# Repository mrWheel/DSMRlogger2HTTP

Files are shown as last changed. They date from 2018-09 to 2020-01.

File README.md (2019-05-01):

# DSMRlogger2HTTP
This repository contains the software for the *Draadloze Slimme Meter Reader*.

<br />

You can find <i>technical</i> documentation for this project at 
<a href="https://mrWheel.github.io/DSMRlogger2HTTP/">https://mrWheel.github.io/DSMRlogger2HTTP </a>
    
<br />

<div style="background:#ADD8E6;">
<br />
    
There is a new repository with new firmware for de DSMR-logger that you can find 
<a href="https://github.com/mrWheel/DSMRloggerWS">here</a>
<br /> &nbsp;
<br />
</div>

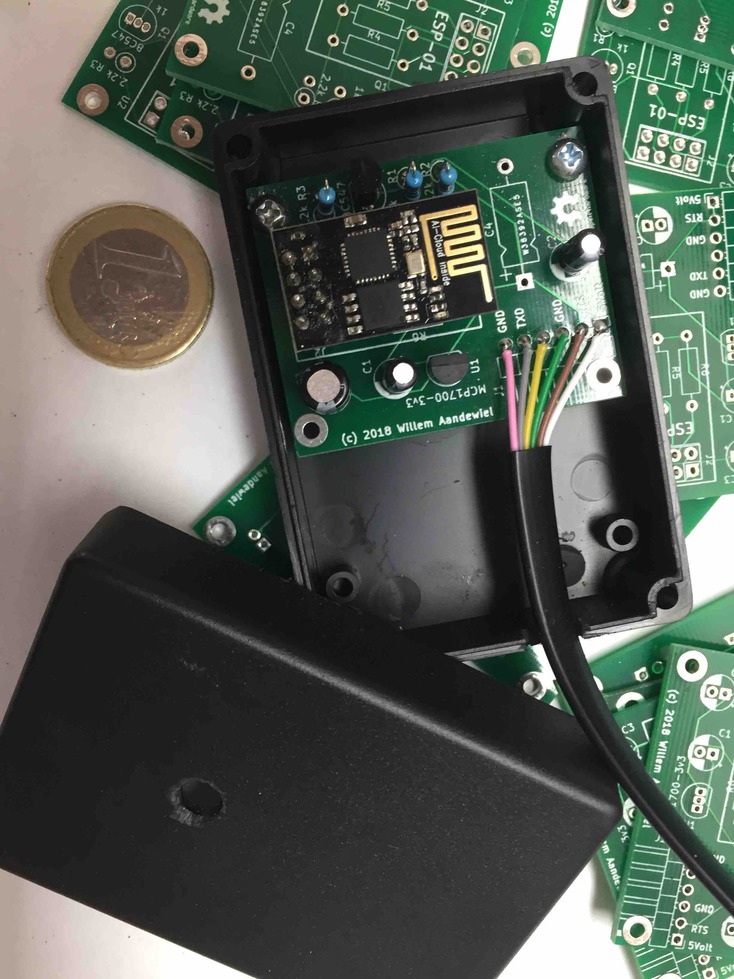
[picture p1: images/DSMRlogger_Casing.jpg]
Completed


Almost all households in the Netherlands are equipped with such a Smart Meter.

The name DSMRlogger is derived from the acronym DSMR which stands for “*Dutch Smart Meter Requirements*“.
The hardware and software should work from **version 4.0** and up of these requirements (as from that version on
the requirements state a 5v output @250mA, which is needed by the DSMRlogger to operate).

Unzip the file into your Arduino Projects directory.

A map "**DSMRlogger2HTML**" will be created with in it all the files necessary to program an ESP01
to function as a “*Slimme Meter Uitlezer*”.

If you use an **ESP01 black** (recommended) than you **must** set the board to:

<code>
Arduino-IDE settings for ESP01 (black):

    - Board: "Generic ESP8266 Module"
    - Flash mode: "DOUT"
    - Flash size: "1M (128K SPIFFS)"
    - Debug port: "Disabled"
    - Debug Level: "None"
    - IwIP Variant: "v2 Lower Memory"
    - Reset Method: "nodemcu"   // <-- this actualy depends on the programmer you use
    - Crystal Frequency: "26 MHz"
    - Flash Frequency: "40MHz"
    - CPU Frequency: "80 MHz"
    - Buildin Led: "1"  // GPIO01 - Pin 2
    - Upload Speed: "115200"
    - Erase Flash: "Only Sketch"
    - Port: "ESP01-DSMR at <-- IP address →"
</code>

For more information see [this post](https://willem.aandewiel.nl/index.php/slimme-meter-uitlezer/).

If you are new to programming the ESP8266 (and you have mastered the Dutch language) I recoment 
[this](https://willem.aandewiel.nl/index.php/aan-de-slag-met-de-esp8266/) post!

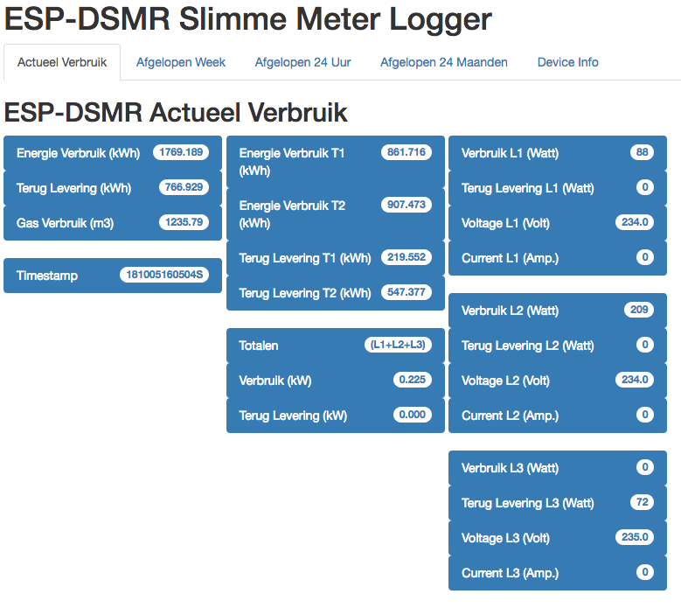
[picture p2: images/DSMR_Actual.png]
Actual

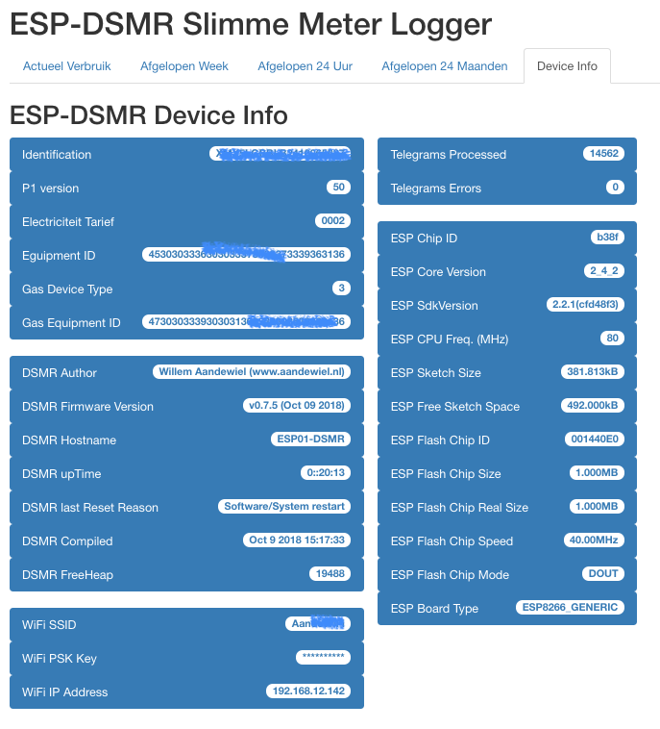
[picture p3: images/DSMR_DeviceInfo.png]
DeviceInfo


If you upload one of the <code>PRDfiles.csv</code>, you need to reboot the ESP01-DSMR before it overwrites the files again from memory to SPIFFS (every change of the hour, day or month).

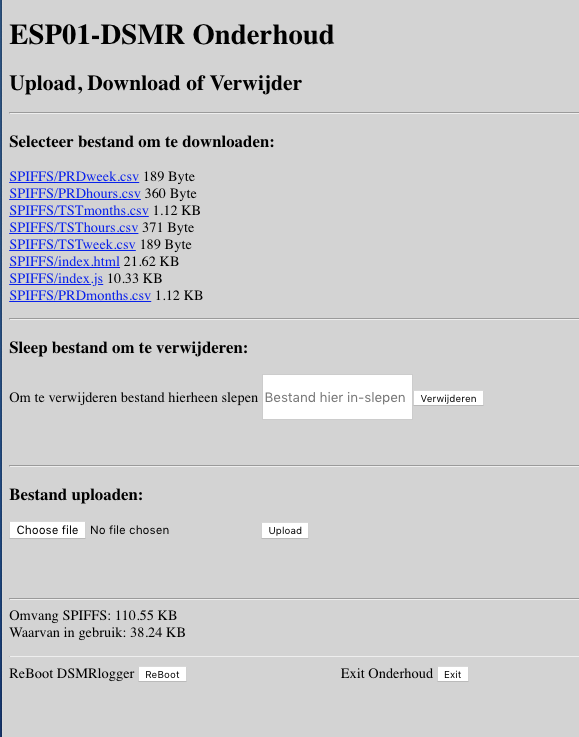
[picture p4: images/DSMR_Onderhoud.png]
Onderhoud


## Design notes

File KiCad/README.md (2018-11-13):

# DSMR-logger PCB v3.0

Here you will find the gerber files for the DSMR-logger

Main changes are:

     - RJ12 connector in stead of soldering the connector wires directly to the PCM
     - Pads for U1 are now further apart
     - Pads for Q1 are now further apart
     - C3 / C2 changed places

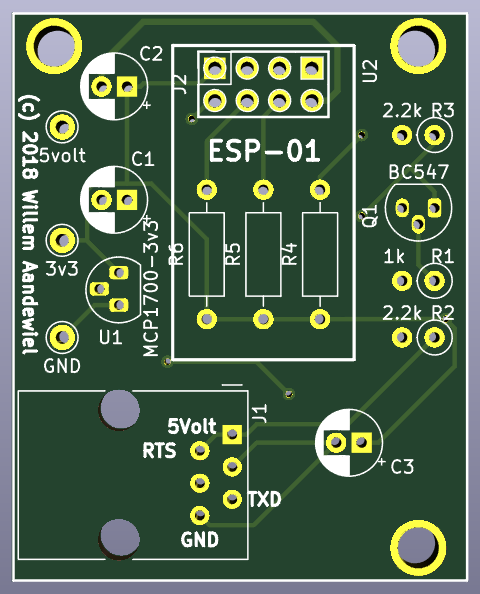
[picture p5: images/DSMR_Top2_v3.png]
Top2

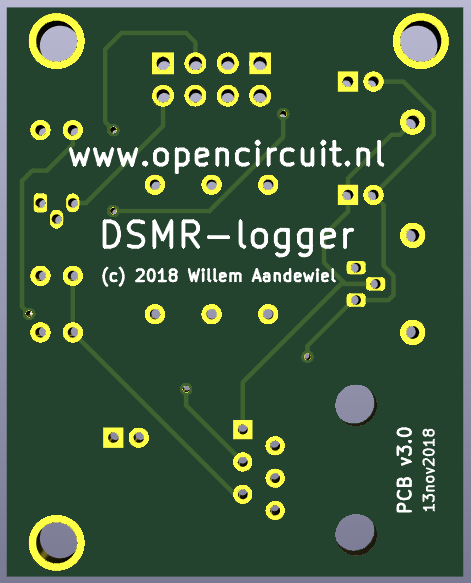
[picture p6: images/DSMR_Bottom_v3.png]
Bottom

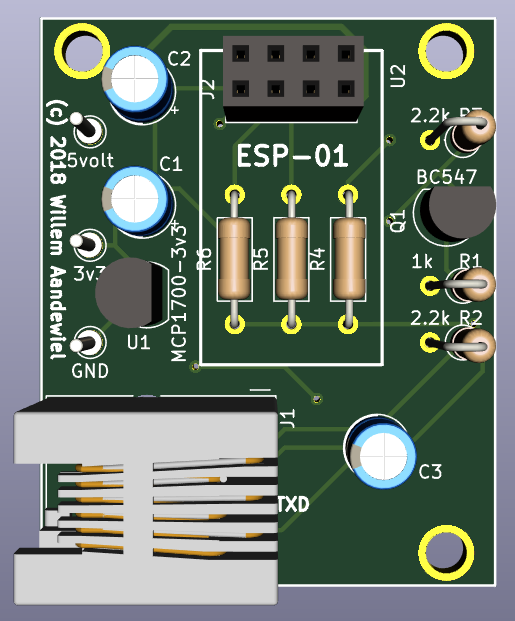
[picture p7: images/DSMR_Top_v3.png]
Top


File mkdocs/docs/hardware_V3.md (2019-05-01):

## DSMR-logger Versie 3

Hoe je een DSMRlogger Versie 2 kunt bouwen staat 
<a href="https://github.com/mrWheel/DSMRlogger2HTTP/blob/master/Bouwbeschrijving.pdf" target="_blank">
hier</a>
uitvoerig beschreven.

Versie 3 is gelijk aan Versie 2 met dit verschil dat de transistor en voltage regulator
eenvoudiger zijn te solderen omdat de pad's verder uit elkaar staan.

Versie 3 heeft ook een RJ12 connector waardoor de draadbreuken die met Versie 2
nog wel eens voorkwamen verleden tijd zijn.

Een bouwpakket voor Versie 3 kun je 
<a href="https://opencircuit.nl/Product/13859/Slimme-meter-uitlezer-V3-bouwpakket-met-ESP-01" target="_blank">
hier</a> bestellen.

### Inhoud Opencircuit bouwpakket 

|Aantal|Itemi |PCB label|
|---|---|---|
|1x|PCB|-|
|1x|ESP8266 ESP-01S|-|
|1x|BC547|Q1|
|1x|MCP1700-3v3|U1|
|1x|1K Ω weerstand (bruin,zwart,rood)|R1|
|2x|2K2 Ω weerstand (rood,rood,rood)|R2,R3|
|3x|10K Ω weerstand (bruin,zwart,oranje)|R4,R5,R6|
|1x|Elco 1µF|C1| 
|1x|Elco 2.2µF|C2| 
|1x|Elco 1000µF|C3| 
|1x|Socket connector 4x2|J2|
|1x|RJ12 Socket connector|J1|
|1x|RJ12 kabel|-|

### Solderen

Begin met de laagste componenten: 

- Plaats: R4, R5 en R6, plaats deze plat. Weerstanden hebben geen polariteit, de richting 
maakt dus niet uit.
- Plaats R1, R2, R3 rechtop. 
- Plaats Q1 en U1 - de soldeer pads zijn klein en liggen dicht bij elkaar, wees 
zorgvuldig en neem de tijd. 

De Elco's hebben wel polariteit, de negatieve pool is herkenbaar aan de lichtere streep op de 
zijkant. Op de PCB is deze kant aangegeven met een witte helft. Daar moet de negatieve pool 
op worden aangesloten.

- Plaats C1, C2 en C3 met de juiste negatieve pool en de correcte Elco.
- Plaats J2 en J1 

Controleer je werk op slechte soldeerverbindingen (het tin droogt dan *mat* op) en
kortsluiting (tin-bruggen tussen twee pad's).

De ESP01 word uiteindelijk in de socket geplaatst, maar moet eerst nog worden geflashed met 
de `DSMRlogger2HTTP` firmware en de `data`-map moet naar SPIFFS worden ge-upload voordat 
hij kan gaan loggen. Hoe dat moet staat [hier](../uploadFirmware_ESP-01) en 
[hier](../uploadDataMap_ESP-01) beschreven.

<br>
---
<center style="font-size: 70%;">[PCB Versie 2]</center><br>

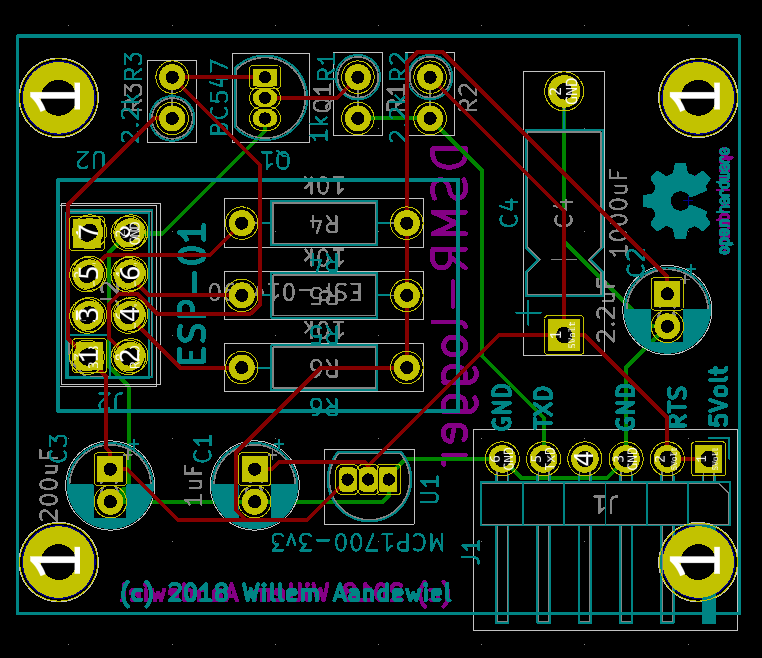
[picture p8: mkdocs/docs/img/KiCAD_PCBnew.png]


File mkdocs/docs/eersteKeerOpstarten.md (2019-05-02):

# Eerste keer opstarten

Haal de ESP01 van de programmer/breadboard af en stop hem in de socket van de logger.
Sluit de logger aan op de P1 poort van de "slimme meter". Hij zal gaan booten en maakt 
zijn eigen accesspoint. Dit kun je zien aan het blauwe ledje wat zal gaan knipperen
en daarna constant blijft branden.

Via je computer/mobiel, bekijk de Wifi netwerken, hier zul je een 
`ESP01‑DSMR‑xx‑<IPaddress>` tussen zien staan: connect aan dit AccessPoint (AP).

Zodra je verbonden bent, open de browser en ga naar ip adres wat de naam van het 
accesspoint staat bijv `192.168.5.1`

- Klik op `Configure WiFi`
- Selecteer je eigen WiFi router
- Typ het password
- Klik save

De logger zal rebooten en verbinding maken met jouw WiFi router

Tijdens het opstarten kun je aan de blauwe led zien wat de DSMR-logger aan het doen is:

- 3 x langzaam knipperen – initiële start
- 5 x snel knipperen – verbinding gemaakt met WiFi netwerk

Daarna knippert de blauwe led iedere keer als er een nieuw telegram verwerkt wordt.

Als de led, na de eerste drie keer langzaam knipperen blijft branden, dan kon de 
DSMR-logger geen verbinding met jouw WiFi netwerk maken en start hij weer zijn eigen 
AP op en zal je WiFi procedure opnieuw moeten doen.

Zodra hij geconnecteerd is open een browser en ga naar:
`http://ESP01-DSMR.local/` of `http://<IPadresVanDeLogger>/`

Als je in de browser de tekst `FileNotFound` ziet, dan ben je waarschijnlijk vergeten 
de Data-map te uploaden met de menu-optie `ESP8266 Sketch Data Upload` in de ArduinoIDE
([kijk hier](uploadDataMap_ESP-01.md) hoe dat moet).

Als alles goed is gegaan zie je in de browser de hoofd-pagina van de DSMR-logger met 
daarin de actuele data uit de Slimme Meter.

Je kunt met `telnet ESP01-DSMR.local` of met `telnet <IPadresVanDeLogger>` inloggen 
op je DSMR-logger en volgen waar de DSMR-logger mee bezig is.

Om te bepalen welk IP is uitgegeven aan de ESP door de DHCP server, kun je in je router 
kijken, of met bijv de Fing app of met `nmap`.

Een andere manier om achter het IP-adres van je DSMR-logger te komen is door de  
ArduinoIDE op te starten. 

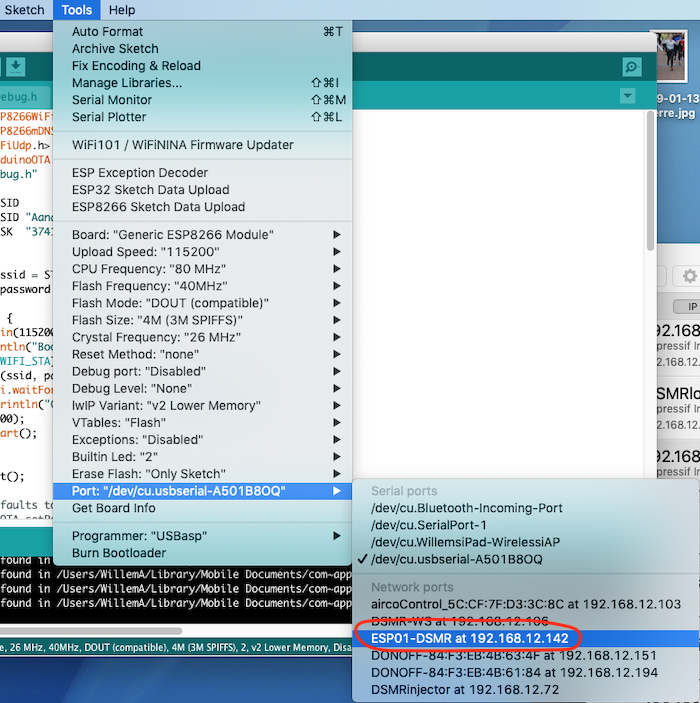
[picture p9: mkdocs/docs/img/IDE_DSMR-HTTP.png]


Onder `Network Ports` staat de `ESP01-DSMR` als optie, met daarachter het IP adres (in dit 
voorbeeld is dat `192.168.12.142`).

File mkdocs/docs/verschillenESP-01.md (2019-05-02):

## Verschillen ESP-01

- ESP-01
- ESP-01 (Black Edition)
- ESP-01S

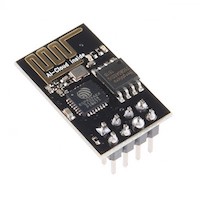
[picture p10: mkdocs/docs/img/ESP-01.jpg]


### ESP-01
De ESP-01 heeft slechts 512MB flash geheugen en is **niet** geschikt voor de DSMR-logger

### ESP-01 (Black Edition)
Dit is de versie van de ESP8266 waar versie 2 en 3 van de DSMR-logger op zijn gebaseerd. 
Deze versie heeft een `rode` power led en een `blauwe` led die op GPIO-01 is 
aangesloten.   
Deze versie heeft `1MB` flash geheugen en is geschikt voor de DSMRlogger2HTTP firmware.

### ESP-01S
Oorspronkelijk had deze ESP-01 ook slecht `512MB` flash geheugen.   
De versie die nu meestal verkocht wordt heeft echter `1MB` geheugen. 
Het is dus wel zaak op te letten wat voor versie je koopt!
De ESP-01S heeft geen power led en de `blauwe led` is niet op GPIO-01 maar op GPIO-02 
aangesloten.  
Deze versie van de ESP-01 is geschikt voor de DSMRlogger2HTTP firmware.

<br>

---
<center style="font-size: 70%">[BOM]<br>
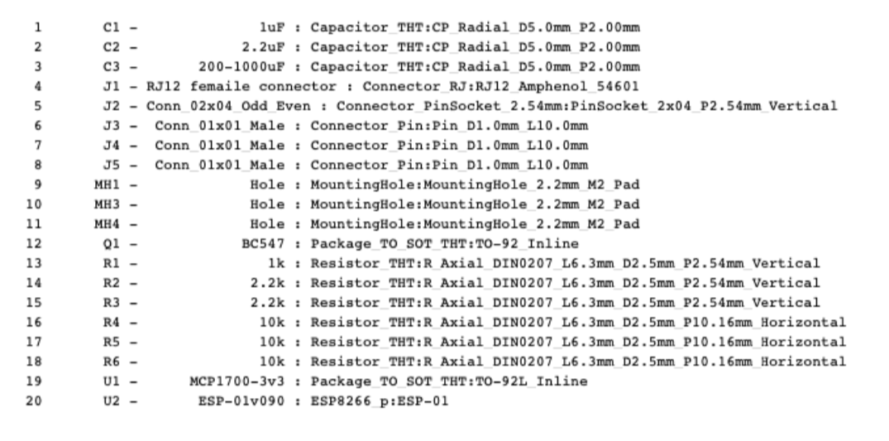
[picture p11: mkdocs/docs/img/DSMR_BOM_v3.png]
</center>

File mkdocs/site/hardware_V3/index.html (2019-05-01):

- Docs »
- Hardware »
- DSMRlogger v3

## DSMR-logger Versie 3

Hoe je een DSMRlogger Versie 2 kunt bouwen staat hier (https://github.com/mrWheel/DSMRlogger2HTTP/blob/master/Bouwbeschrijving.pdf) uitvoerig beschreven.

Versie 3 is gelijk aan Versie 2 met dit verschil dat de transistor en voltage regulator eenvoudiger zijn te solderen omdat de pad's verder uit elkaar staan.

Versie 3 heeft ook een RJ12 connector waardoor de draadbreuken die met Versie 2 nog wel eens voorkwamen verleden tijd zijn.

Een bouwpakket voor Versie 3 kun je hier (https://opencircuit.nl/Product/13859/Slimme-meter-uitlezer-V3-bouwpakket-met-ESP-01) bestellen.

### Inhoud Opencircuit bouwpakket

Aantal | Itemi | PCB label
1x | PCB | -
1x | ESP8266 ESP-01S | -
1x | BC547 | Q1
1x | MCP1700-3v3 | U1
1x | 1K Ω weerstand (bruin,zwart,rood) | R1
2x | 2K2 Ω weerstand (rood,rood,rood) | R2,R3
3x | 10K Ω weerstand (bruin,zwart,oranje) | R4,R5,R6
1x | Elco 1µF | C1
1x | Elco 2.2µF | C2
1x | Elco 1000µF | C3
1x | Socket connector 4x2 | J2
1x | RJ12 Socket connector | J1
1x | RJ12 kabel | -

### Solderen

Begin met de laagste componenten:

- Plaats: R4, R5 en R6, plaats deze plat. Weerstanden hebben geen polariteit, de richting maakt dus niet uit.
- Plaats R1, R2, R3 rechtop.
- Plaats Q1 en U1 - de soldeer pads zijn klein en liggen dicht bij elkaar, wees zorgvuldig en neem de tijd.

De Elco's hebben wel polariteit, de negatieve pool is herkenbaar aan de lichtere streep op de zijkant. Op de PCB is deze kant aangegeven met een witte helft. Daar moet de negatieve pool op worden aangesloten.

- Plaats C1, C2 en C3 met de juiste negatieve pool en de correcte Elco.
- Plaats J2 en J1

Controleer je werk op slechte soldeerverbindingen (het tin droogt dan mat op) en kortsluiting (tin-bruggen tussen twee pad's).

De ESP01 word uiteindelijk in de socket geplaatst, maar moet eerst nog worden geflashed met de DSMRlogger2HTTP firmware en de data-map moet naar SPIFFS worden ge-upload voordat hij kan gaan loggen. Hoe dat moet staat hier en hier beschreven.

[PCB Versie 2]



Next Previous

copyright © 2018 - 2019 Willem Aandewiel

Built with MkDocs (http://www.mkdocs.org) using a theme (https://github.com/snide/sphinx_rtd_theme) provided by Read the Docs (https://readthedocs.org).

« Previous Next »

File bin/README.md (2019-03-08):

# Binary voor ESP-01 

## 1)
Download, als zip file, de laatste versie van DSMRlogger2HTTP van github

### 1.1)
Als je het zipfile download, pak deze dan uit (unzip) en kopieer de map 
```DSMRlogger2HTTP-master``` naar je Arduino projecten directory met de naam ```DSMRlogger2HTTP``` (let
op, het deel '**-master**' moet je dus weghalen!).

In de map staan nu twee andere mappen die van belang zijn. '**/bin**' want hier staat het binary file in dat we naar de ESP-01 gaan uploaden en '**/data**' waar de bestanden voor het file-systeem in staan.

### 1.2)
Je kunt de repository ook clonen. Ga hiervoor in de Arduino projecten directory staan en toets het volgende commando in:

```
    git clone https://github.com/mrWheel/DSMRlogger2HTTP.git
```

Zoek in de (nieuwe) map ```DSMRlogger2HTTP/bin/``` het binary file met de nieuwe firmware. Onthou het pad hier naartoe.

## 2) Voor update "Over The Air":

### 2.1) 
Zoek uit waar jouw versie van '**espota.py**' staat
### 2.2) 
Zoek uit wat het IPaddress van je ESP-01 is (kijk in de IDE bij [port]/[network ports])
### 2.3) 
Onthou waar je de binary van **DSMRlogger2HTTP_v6.ino.bin** heb opgeslagen.
### 2.4) 
Toets het commando in zoals hier onder weergegeven, maar vervang alle variabelen met wat je hiervoor hebt uitgezocht!
```
    python <path naar: 'espota.py'> -i <IPaddress ESP-01> -p 8266 --auth= -f <path naar 'DSMRlogger2HTTP_v6.ino.bin'>
```

*LET OP: de quotjes ('), kleiner-dan (<) en groter-dan (>) tekens moet je niet intoetsen!!*

## 3) Voor update naar een, via een kabel verbonden, programmer voor de ESP-01:

### 3.1)
Zoek uit waar jouw versie van '**esptool**' staat
### 3.2)
Zoek uit op welke (USB)poort de programmer voor de ESP-01 is aangesloten
### 3.3)
Onthou waar je de binary van ```DSMRlogger2HTTP_v6.ino.bin``` heb opgeslagen.
### 3.4)
Toets het commando in zoals hier onder weergegeven, maar vervang alle variabelen met wat je hiervoor hebt uitgezocht!

```
  <path naar: 'esptool'> -vv -cd nodemcu -cb 115200 -cp <USBpoort> -ca 0x00000 -cf <path naar 'DSMRlogger2HTTP_v6.ino.bin'>
```

*LET OP: de quotjes ('), kleiner-dan (<) en groter-dan (>) tekens moet je niet intoetsen!!*

## 4)
Start nu de ArduinoIDE op, selecteer het programma ```DSMRlogger2HTTP```.

## 5)
Selecteer in [**Tools**] de correcte settings voor het ESP-01 board.

    - Board: "Generic ESP8266 Module"
    - Flash mode: "DOUT"
    - Flash size: "1M (128K SPIFFS)"
    - Debug port: "Disabled"
    - Debug Level: "None"
    - IwIP Variant: "v2 Lower Memory"
    - Reset Method: "nodemcu"   // <-- dit is afhankelijk van de programmer die je gebruikt
    - Crystal Frequency: "26 MHz" (otherwise Serial output is garbidge)
    - VTables: "Flash"
    - Flash Frequency: "40MHz"
    - CPU Frequency: "80 MHz"
    - Buildin Led: "1"  // GPIO01 - Pin 2
    - Upload Speed: "115200"
    - Erase Flash: "Only Sketch"
    - Port: "ESP01-DSMR at <-- IP address -->" of USB poort

Klik nu [**Tools**] -> [**ESP8266 Sketch Data Upload**] aan. Nu wordt het filesysteem, inclusief de benodigde bestanden (met name **index.html** en **index.js**) in het SPIFFS bestands-systeem gezet!

## 6)
Klaar!

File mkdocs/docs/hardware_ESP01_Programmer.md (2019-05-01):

## Programmer voor de ESP-01

Je kunt 
<a href="https://willem.aandewiel.nl/index.php/2018/08/27/eenvoudige-programmer-voor-de-esp-01-esp8266/" target="_blank">hier</a>
(www.aandewiel.nl) een post vinden met instructies hoe je eenvoudige een programmer
voor de ESP-01 kunt maken.

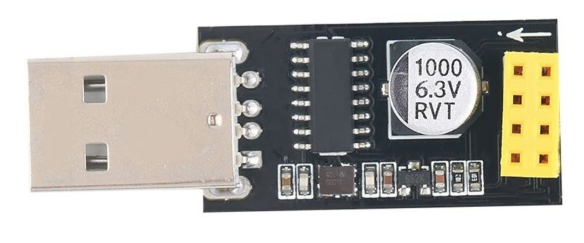
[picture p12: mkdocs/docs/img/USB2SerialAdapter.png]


<br>

---
<center style="font-size: 70%;">[DSMR-logger v3]</center><br>



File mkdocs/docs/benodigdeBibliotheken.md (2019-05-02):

## Benodigde Bibliotheken

Voor de **DSMRlogger2HTTP** firmware zijn de volgende bibliotheken nodig:

### dsmr
Deze library is ontwikkeld door *Matthijs Kooijman* en vormt het hart van de
DSMR-logger. Je kunt de bibliotheek hier
<a href="https://github.com/matthijskooijman/arduino-dsmr" target="_blank">
https://github.com/matthijskooijman/arduino-dsmr</a>
downloaden.   
De firmware is getest met `Version 0.1 - Commit f79c906 on 18 Sep 2018`.

### TimeLib
Deze is door *Paul Stoffregen* ontwikkeld. Je kunt hem hier
<a href="https://github.com/PaulStoffregen/Time" target="_blank">
https://github.com/PaulStoffregen/Time</a>
downloaden.

### WiFiManager
Je kunt de, door *Tzapu* ontwikkelde, bibliotheek hier
<a href="https://github.com/tzapu/WiFiManager" target="_blank">
https://github.com/tzapu/WiFiManager</a>
downloaden.   
De DSMR-logger firmware is getest met `version 0.14.0` van deze bibliotheek.

### TelnetStream
Deze bibliotheek is door *Jan Drassy* ontwikkeld.
Je kunt deze bibliotheek hier
<a href="https://github.com/jandrassy/TelnetStream" target="_blank">
https://github.com/jandrassy/TelnetStream</a>
downloaden.   
De firmware is getest met `version 0.0.1`.

**Let op:** De installatie van deze bibliotheek gaat net als de andere bibliotheken. Een update 
kan echter pas geïnstalleerd worden als éérst de map `TelnetStream-master` uit de
map `Libraries` wordt verwijderd! 

### Overige libraries
Onderstaande libraries zijn onderdeel van de `ESP8266 Core` **en moeten dus niet handmatig
geïnstalleerd worden**!

	* ESP8266WiFi    
	* ESP8266WebServer
	* FS           
	* ArduinoOTA  

<br>

---
<center style="font-size: 70%">[Slimme Meter]</center><br>
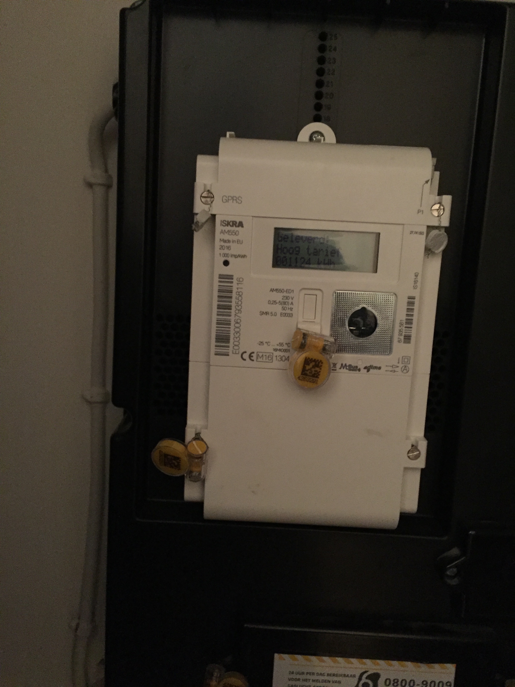
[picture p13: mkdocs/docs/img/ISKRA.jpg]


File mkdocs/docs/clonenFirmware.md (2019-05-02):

## Clonen Firmware
De **DSMRlogger2HTTP** firmware staat hier
<a href="https://github.com/mrWheel/DSMRlogger2HTTP" target="_blank">
https://github.com/mrWheel/DSMRlogger2HTTP</a>.

Er zijn twee manieren om de firmware te clonen.

1. download de repository als een `.zip` file
2. gebruik `git`

Als je niet handig bent met `git` raad ik je aan de repository als een `.zip` file te downloaden.

<hr>
### Download .zip file

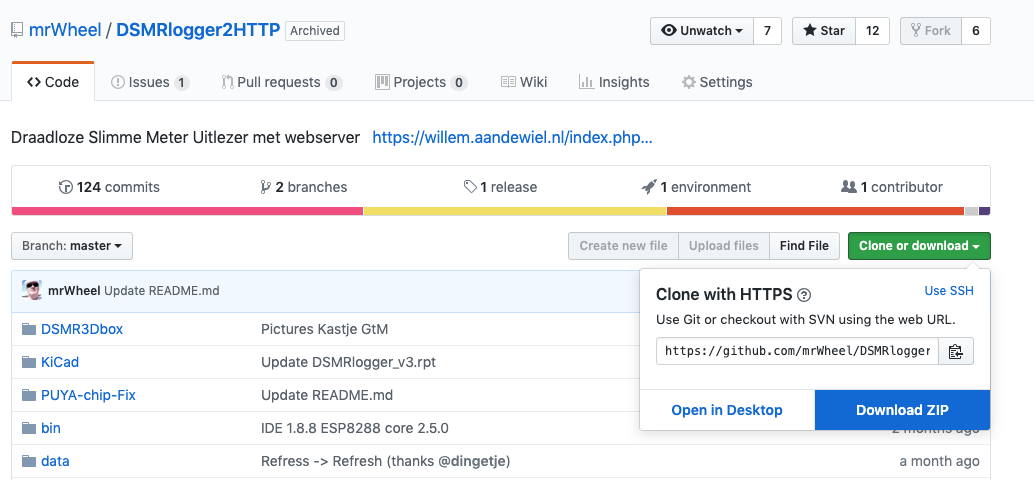
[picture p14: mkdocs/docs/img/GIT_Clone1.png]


Klik op de groene knop 
<span style="background: green; color: white;">[Clone or Download]</span>
en selecteer 
<span style="background: blue; color: white;">[Download ZIP]</span>

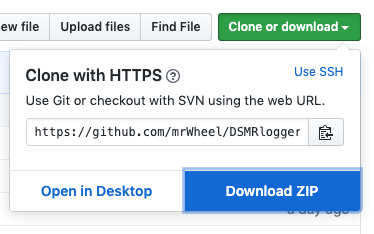
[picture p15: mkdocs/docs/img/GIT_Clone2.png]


Er volgt een scherm als dit:

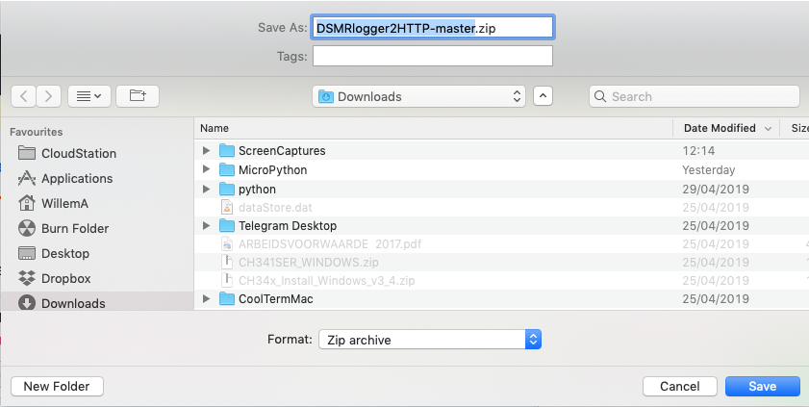
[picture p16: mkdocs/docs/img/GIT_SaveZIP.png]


1. Bewaar het `.zip` bestand op een plek op je computer waar je hem terug kunt vinden.
2. Unzip het `DSMRlogger2HTTP-master.zip` bestand in de ArduinoIDE `Sketchbook Location`.
3. Rename de map `DSMRlogger2HTTP-master` naar `DSMRlogger2HTTP` (dus zonder `-master`)

Ga verder naar [DSMRlogger2HTTP Sketch openen](#dsmrlogger2http-sketch-openen)

<hr>
### git clone
Om de repository met `git` te kunnen clonen moet je er éérst voor zorgen dat je `git` 
op je systeem hebt staan. Hoe je dat moet doen valt buiten de scope van deze documentatie
maar
<a href="https://git-scm.com/book/nl/v1/Aan-de-slag-Git-installeren" target="_blank">
hier</a>
kun je alles vinden over hoe je dit, voor jouw systeem, moet doen.

Voor nu ga ik ervan uit dat je `git` op je systeem hebt staan en dat je weet hoe je
ermee moet werken.

Ga naar de Arduino `Sketchbook location` (de map waar al je Sketches in staan, 
[kijk hier](installatieESP8266core.md))
en toets het volgende commando in:
```
git clone https://github.com/mrWheel/DSMRlogger2HTTP.git
```
That's it!

In `Sketchbook location` staat hierna een nieuwe map met de naam `DSMRlogger2HTTP`. 

<hr>
### DSMRlogger2HTTP Sketch openen
Start de ArduinoIDE ***opnieuw*** op en klik op het `open` icoon 
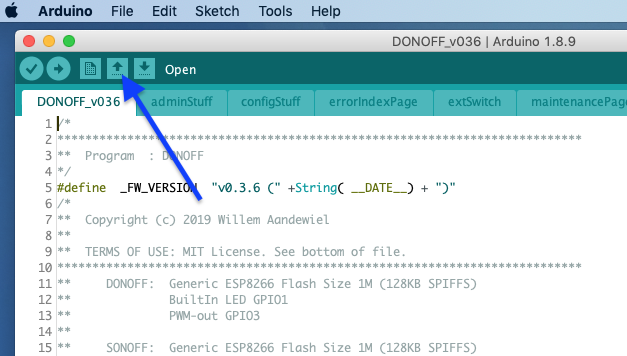
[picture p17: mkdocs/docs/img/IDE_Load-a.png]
.

Selecteer in het `drop-down` menu ..

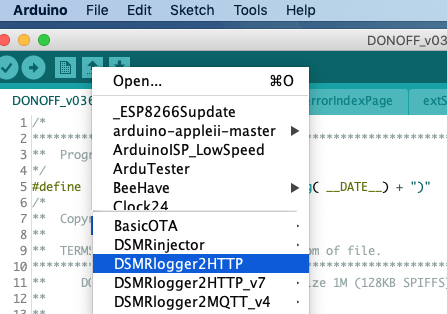
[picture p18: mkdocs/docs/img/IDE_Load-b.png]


.. de sketch `DSMRlogger2HTTP`<br>
Er verschijnt een nieuw editor window met de firmware van de DSMRlogger!

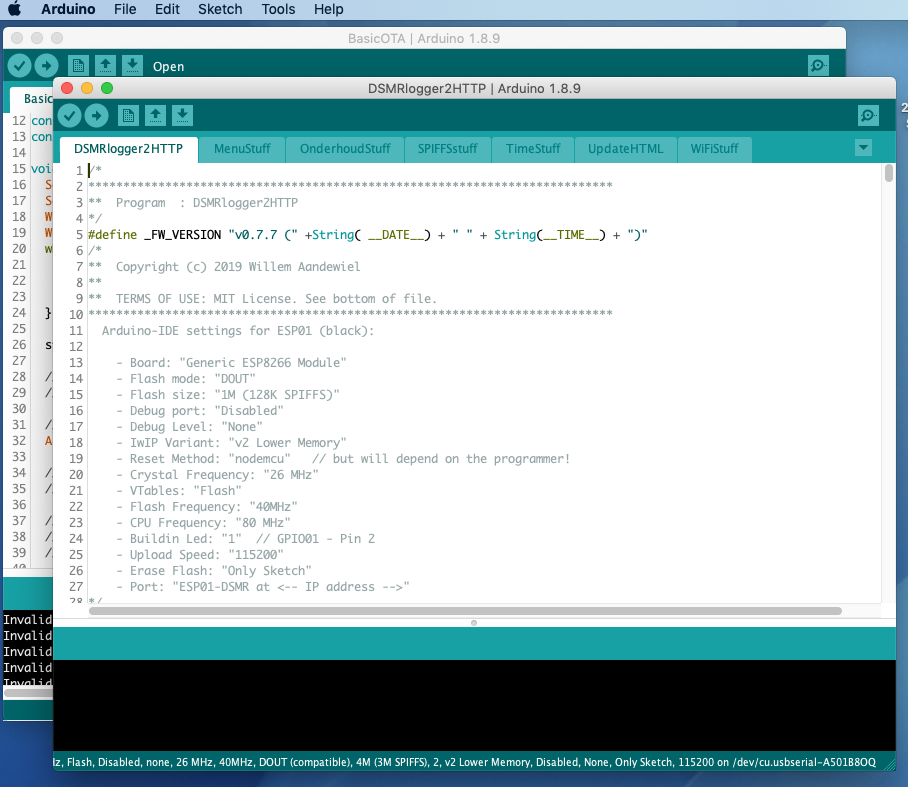
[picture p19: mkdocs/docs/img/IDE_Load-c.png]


<br>

----
<center style="font-size: 70%">[DSMR 3D]</center><br>
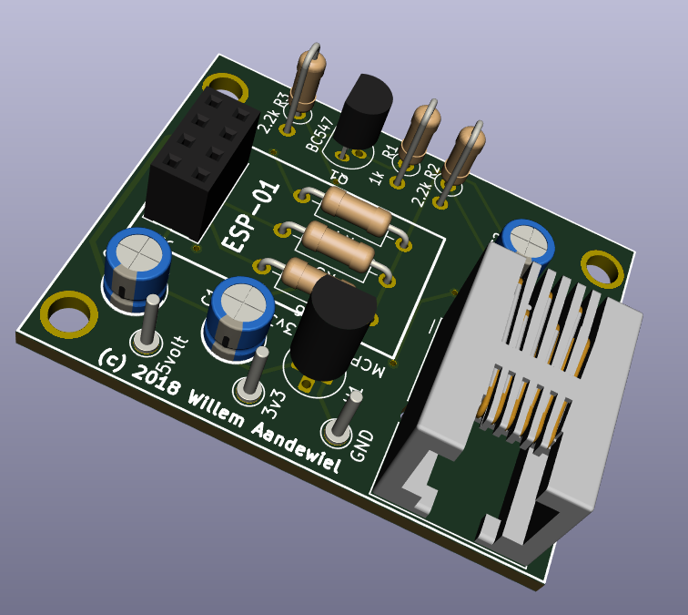
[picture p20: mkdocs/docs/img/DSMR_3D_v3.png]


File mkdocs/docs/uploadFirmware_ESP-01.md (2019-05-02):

## Firmware naar ESP-01 Flashen
Om de firmware naar de ESP-01 (Black/S) te kunnen flashen moet deze eerst 
voor deze ESP-01 geschikt worden gemaakt.

Dit doen we door vóór de `#define HAS_NO_METER` twee *slashes* (**//**) te zetten.
```
/******************** change this for testing only **********************************/
// #define HAS_NO_METER          // define if No "Slimme Meter" is attached
/******************** don't change enything below this comment **********************/

```

Vervolgens moeten de [`Boards`] settings als volgt worden ingevuld:

| | Instelling |Waarde|
|:-:|:---|:-----|
| | Board | "Generic ESP8266 Module" |
| | Upload Speed | "115200" |
| | CPU Frequency | "80MHz" |
| | Flash Frequency | "40MHz" |
| | Flash Mode | "DOUT (compatible)" |
| | Flash Size | "1M (256K SPIFFS)" |
| | Crystal Frequency | "26MHz" |
| | Reset Method | "None" |
| | Debug Port | "Disabled" |
| | Debug Level | "None" |
| | IwIP Variant | "v2 Lower Memory" |
| | VTables | "Flash" |
| | Exeptions | "Disabled" |
| | Builtin Led | ESP-01 (Black): "1" <br> ESP-01S: "2" |
| | Erase Flash | "Only Sketch"<br>(First Time: "All Flash Contents") |
| | Port | Bedraad: "Serial Port" <br> OTA: "Netwerk Port" |

Stop de ESP-01 in de programmer 
(<a href="https://willem.aandewiel.nl/index.php/2018/08/27/eenvoudige-programmer-voor-de-esp-01-esp8266/" target="_blank">
hier</a>
vind je een post over hoe je van een `USB to ESP-01
Adapter` zelf eenvoudig een programmer kunt maken) en sluit deze aan op je computer.
Vergeet niet de juiste `Port` te selecteren en druk op het *Compile and Upload icoon*.

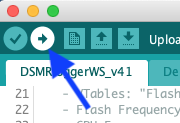
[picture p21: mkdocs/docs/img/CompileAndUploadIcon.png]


<br>

---
<center  style="font-size: 70%">[DSMR Onderhoud]</center><br>


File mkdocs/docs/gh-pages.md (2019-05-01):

# Github pages onderhouden

Voer, in een command window, de volgende commando's in:

````
cd <waar je de boel wilt hebben>
git clone https://github.com/mrWheel/DSMRloggerHTTP.git

cd DSMRloggerHTTP

git checkout gh-pages

cd mkdocs
````

In de `mkdocs` map zit een map `docs` met daarin alle `.md` bestanden.
Pas deze naar hartelust aan.

Je kunt vervolgens lokaal een server starten met het commando:
````
mkdocs serve
````

Ga vervolgens met een browser naar `http://127.0.0.1:8000` om
je werk te bekijken.

Als je tevreden bent dan moet je de aangepaste sources naar github 
pushen:
````
mkdocs build
mkdocs gh-deploy

git add mkdocs
git commit -m "reden van deze commit"
git push -u origin gh-pages
````

Klaar!

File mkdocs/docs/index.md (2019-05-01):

# Documentatie DSMRlogger2HTTP

Voor de project beschrijving ga naar 
<a href="https://willem.aandewiel.nl/index.php/2018/08/28/slimme-meter-uitlezer/" target="_blank">
www.aandewiel.nl</a>

## Inhoudsopgave

* [Introductie](introductie.md)
* Voorbereiding
    *  [ArduinoIDE](installatieArduinoIDE.md)
    *  [ESP8266 core](installatieESP8266core.md)
    *  [Data Upload Tool](installatieDataUploadTool.md)
* Firmware
    *  [Benodigd Bibliotheken](benodigdeBibliotheken.md)
    *  [Installeren Bibliotheken](installatieBibliotheken.md)
    *  [DSMR Firmware van Github](clonenFirmware.md)
    *  [Firmware Flashen ESP-01](uploadFirmware_ESP-01.md)
    *  [Data Flashen naar ESP-01](uploadDataMap_ESP-01.md)
* Hardware
    *  [DSMR-logger Versie 3](hardware_V3.md)
    *  [Programmer voor de ESP-01](hardware_ESP01_Programmer.md)
* Overigen
    * [Eeste keer opstarten](eersteKeerOpstarten.md)
    * [Verschillen ESP-01 modules](verschillenESP-01.md)

<br>

---
<center  style="font-size: 70%">[ScreenShot DSMR-Actueel]</center><br>
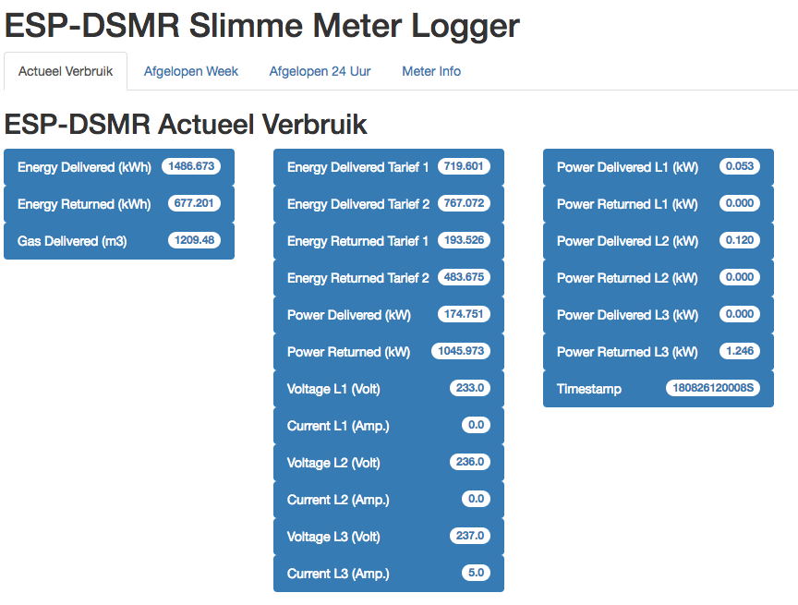
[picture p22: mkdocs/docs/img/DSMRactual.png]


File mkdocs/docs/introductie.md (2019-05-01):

## Introductie
Dit is de documentatie voor de DSMR-logger v2 en v3 en de DSMRlogger2HTTP firmware.   

Ga voor de volledige project beschrijving naar 
<a href="https://willem.aandewiel.nl/index.php/2018/08/28/slimme-meter-uitlezer/" target="_blank">
www.aandewiel.nl</a>

#### Het idee
Zo langzamerhand zijn alle huizen in Nederland uitgerust met een “Slimme Meter”. 
Deze meters beschikken over een "P1" poort, deze poort kan worden uitgelezen. 
Dit project stelt je in staat dit zelf thuis uit te lezen en de gegevens op een 
door jouw gewenst formaat te presenteren dmv een "DSMR logger". Er zijn 
commerciele P1 oplossingen beschikbaar, dit project geeft je aanzienlijk meer 
controle over de kosten en de gegevens. 

<a href="https://nl.wikipedia.org/wiki/Slimme_meter" target="_blank">DSMR</a> 
is een acroniem voor *Dutch Smart Meter Requirements*

De doelstellingen van de DSMR logger project zijn:

- Moet eenvoudig en goedkoop gemaakt kunnen worden;
- Moet “Over The Air” ge-update kunnen worden;
- Moet een beperkte historie hebben die intern opgeslagen wordt;
- Moet via een externe terminal benaderd kunnen worden (telnet);
- Moet via een browser de gegevens kunnen presenteren;
- Moet via een REST API de gegevens kunnen leveren;
- Moet gegevens eenvoudig verder laten verwerken.

De DSMR-logger is een hardware en software systeem waarmee de Slimme Meter 
(vanaf *DSMR* versie 4.0) kan worden uitgelezen. De uitgelezen data (telegrammen) 
worden in de DSMR-logger opgeslagen en kunnen in de vorm van tabellen en 
charts, via WiFi, op een computer of tablet worden weergegeven.

<div class="admonition note">
<p class="admonition-title">Begrippen</p>
In dit document worden de volgende begrippen gebruikt:
<table>
<tr><th align="left">Begrip</th><th align="left">Omschrijving</th></tr>
<tr>
	<td style="vertical-align:top">DSMR-logger</td>
	<td>de Hardware</td>
</tr>
<tr>
	<td style="vertical-align:top">DSMR-logger v2 (of Versie 2)</td>
	<td>Versie 2 van de Hardware
            <br>Dit is de hardware van de DSMR-logger die is uitgerust 
            <br>met een ESP-01 (Black/S) bordje.
	    <br>Voor deze versie is de firmware DSMRlogger2HTTP bedoeld.
        </td>
</tr>
<tr>
	<td style="vertical-align:top">DSMR-logger v3 (of Versie 3)</td>
	<td>Versie 3 van de Hardware
	    <br>Verder gelijk aan Versie 2.
        </td>
</tr>
<tr>
	<td style="vertical-align:top">DSMRlogger2HTTP</td>
	<td>De firmware voor de DSMR-logger v2 en v3</td></tr>
<tr>
	<td style="vertical-align:top">ESP-01</td>
	<td>Een bordje met een ESP8266 processor
	    <br>en 512KB flash geheugen
	    <br>Dit bordje is <b>niet</b> geschikt voor dit project
	</td>
</tr>
<tr>
	<td style="vertical-align:top">ESP-01 (Black)</td>
	<td>Een ESP-01 met 1MB flash geheugen
            <br>Dit bordje heeft een rode Power Led en een blauwe Led op GPIO-01
        </td>
</tr>
<tr>
	<td style="vertical-align:top">ESP-01S</td>
	<td>Een ESP-01 met 1MB flash geheugen
            <br>Dit bordje heeft alleen een blauwe Led op GPIO-02
        </td>
</tr>
<tr>
	<td style="vertical-align:top">ESP-01(Black/S)</td>
	<td>Een ESP-01 Black of ESP-01S
            <br>DSMR-logger v2 en v3 maken gebruik van dit bordje
        </td>
</tr>
</table>
</div>
Een volledige beschrijving van dit project kun je hier:
<a href="https://willem.aandewiel.nl/index.php/2018/08/28/slimme-meter-uitlezer/" target="_blank">
www.aandewiel.nl</a>
vinden.

<br>

---
<center  style="font-size: 70%">[DSMRlogger v2]</center><br>
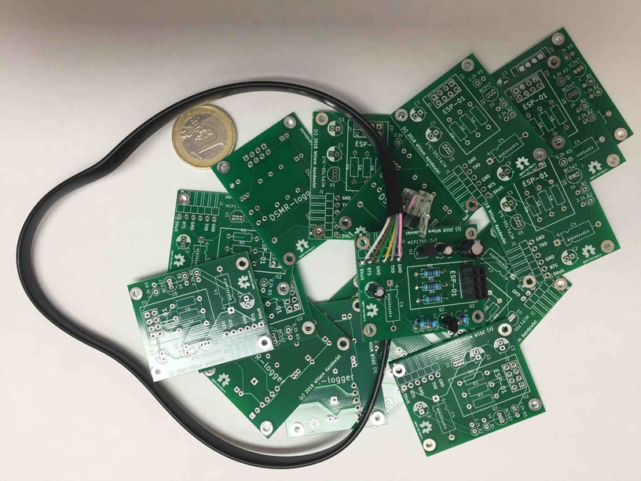
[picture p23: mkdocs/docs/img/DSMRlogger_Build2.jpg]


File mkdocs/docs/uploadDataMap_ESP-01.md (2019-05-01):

## upload Data map naar ESP-01
De `data`-map van de DSMRlogger2HTTP firmware kan zowel via een programmer
als `Over The Air` naar de ESP-01 worden overgezet.

Je kunt 
<a href="https://willem.aandewiel.nl/index.php/2018/08/27/eenvoudige-programmer-voor-de-esp-01-esp8266/" target="_blank">hier</a>
een uitvoerige post vinden over hoe je zelf een eenvoudige programmer voor de
ESP-01 kunt maken en hoe je die vervolgens moet gebruiken om de 
*DSMRlogger2HTTP* firmware en `data`-map naar de ESP-01 te uploaden.

Uiteraard kun je hiervoor ook iedere andere geschikte programmer gebruiken!

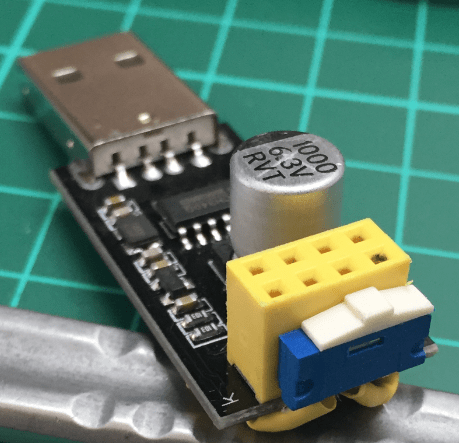
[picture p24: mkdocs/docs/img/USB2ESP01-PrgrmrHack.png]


Als je de ESP-01 op de programmer hebt aangesloten en deze staat in "Flash-Mode"
ga dan in de Arduino IDE naar `Tools`** -> **`ESP8266 Sketch Data Upload` <br>

SPIFFS wordt nu leeg gemaakt en alle bestanden in de `data`-map worden naar het SPIFFS overgezet.

Hierna zal de DSMR-logger normaal opstarten, maar met de nieuw SPIFFS inhoud.

<div class="admonition note">
<p class="admonition-title">Let op!</p>
Hou er rekening mee dat eventuele data-bestanden die al op SPIFFS stonden nu weg zijn! 
Als je ze niet kwijt wil moet je er eerst een kopie van maken op je computer en deze, 
na het flashen van SPIFFS weer terug zetten (dat kan met behulp van de 
<b>/onderhoud</b> pagina)!
</div>

<br>

---
<center style="font-size: 70%;">[DSMR-logger v3]</center><br>

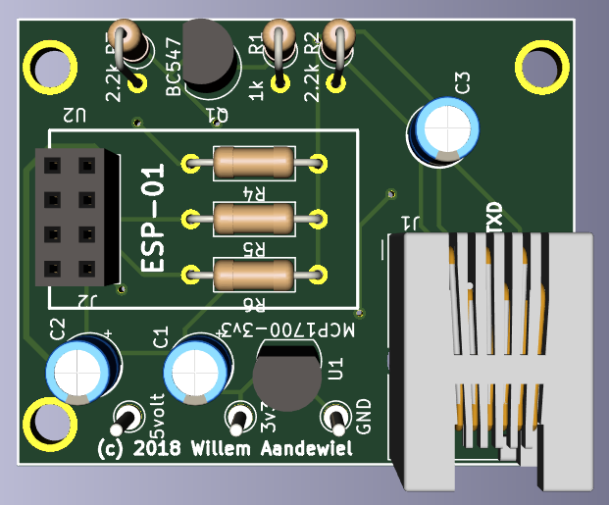
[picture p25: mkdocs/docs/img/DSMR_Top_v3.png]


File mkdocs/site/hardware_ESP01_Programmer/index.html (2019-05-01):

- Docs »
- Hardware »
- Programmer ESP-01

## Programmer voor de ESP-01

Je kunt hier (https://willem.aandewiel.nl/index.php/2018/08/27/eenvoudige-programmer-voor-de-esp-01-esp8266/) (www.aandewiel.nl) een post vinden met instructies hoe je eenvoudige een programmer voor de ESP-01 kunt maken.



[DSMR-logger v3]



Next Previous

copyright © 2018 - 2019 Willem Aandewiel

Built with MkDocs (http://www.mkdocs.org) using a theme (https://github.com/snide/sphinx_rtd_theme) provided by Read the Docs (https://readthedocs.org).

« Previous Next »

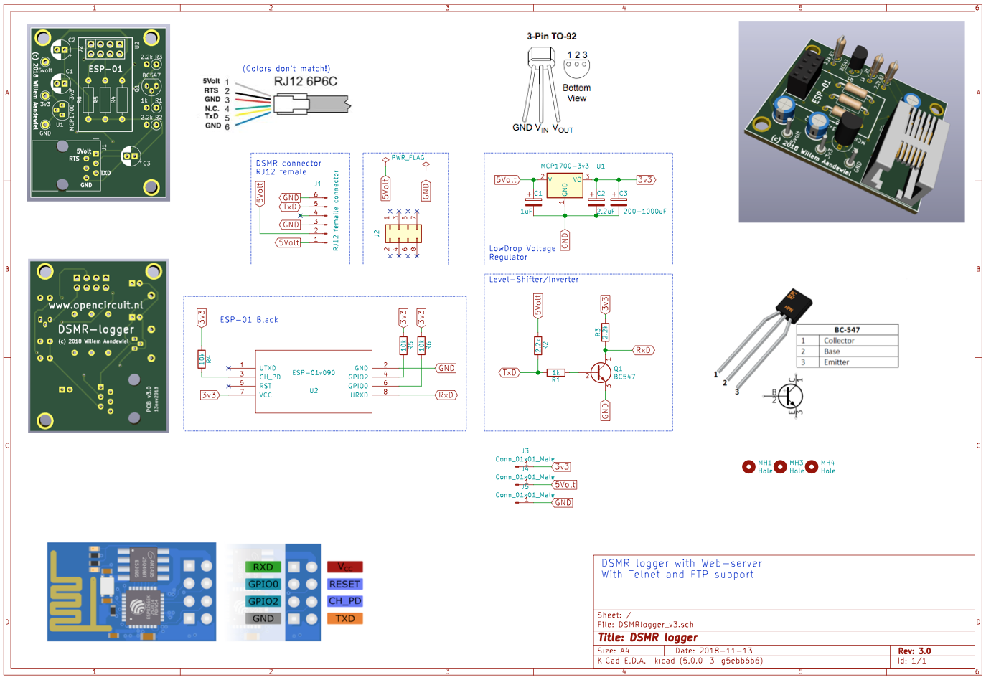
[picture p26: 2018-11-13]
images/DSMR_Schematic_v3.png

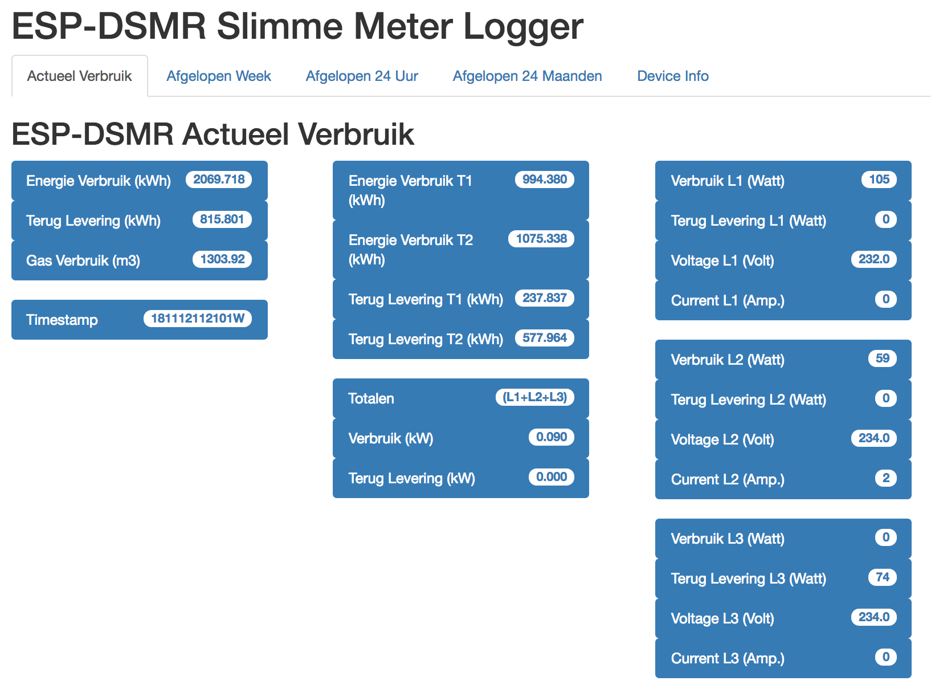
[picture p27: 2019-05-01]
mkdocs/docs/img/DSMR_Actueel.png

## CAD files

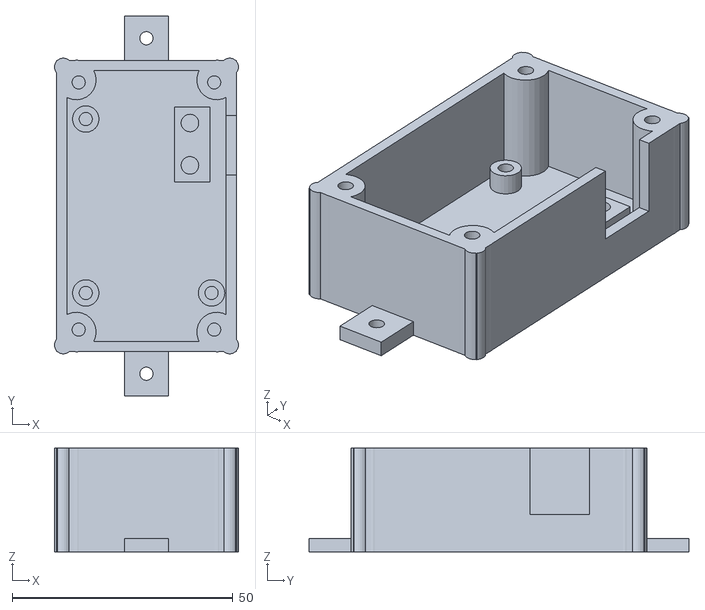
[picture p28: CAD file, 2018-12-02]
DSMR3Dbox/kastje voor slimme meter rj12 variant-1.stl
41.7 x 86.0 x 23.5

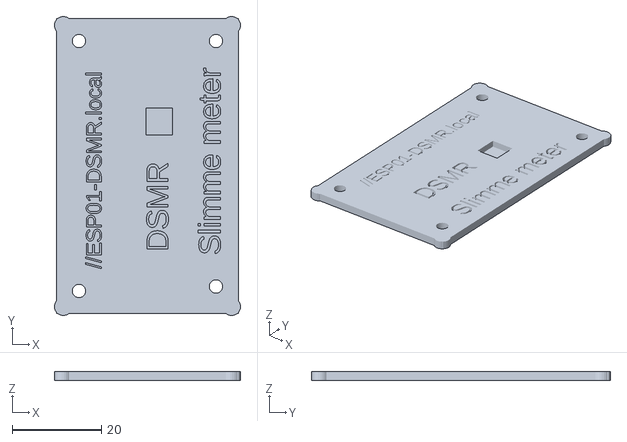
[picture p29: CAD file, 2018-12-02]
DSMR3Dbox/bovenplaat slimme meterrj12.stl
41.7 x 67.0 x 2.00

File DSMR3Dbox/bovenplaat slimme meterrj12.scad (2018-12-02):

xmax=40.7;
ymax=66;
dikte=2;
$fn=25;
zmax=dikte;
gat_top=5.0;
hoeksupport=8;
difference()
{union()
{//translate([dikte*1.13,dikte*1.13,0])
cube([xmax,ymax,dikte]);
   // klein stukje uit de hoek
 translate([1.5,1.5,0])
   cylinder(r=2,h=zmax);
 translate([1.5,ymax-1.5,0])
   cylinder(r=2,h=zmax);
 translate([xmax-1.5,1.5,0])
   cylinder(r=2,h=zmax);
 translate([xmax-1.5,ymax-1.5,0])
   cylinder(r=2,h=zmax);       
}
translate([25,10,1])
    linear_extrude(height=2)
    rotate([0,0,90])
    text("  DSMR",size=5,halign=1,valign=1);
 translate([gat_top,gat_top,0]) 
     cylinder(h=zmax+1,d=3);
 translate([xmax-gat_top,6,0])  
     cylinder(h=zmax+1,d=3);
 translate([gat_top,ymax-gat_top,0])  
     cylinder(h=zmax+1,d=3);
 translate([xmax-gat_top,ymax-gat_top,0])  
     cylinder(h=zmax+1,d=3);
 
    // venstertje om led beter te zien
   translate([20,40,0.4])
   cube([6,6,3]);
     translate([10,10,1])
    linear_extrude(height=2)
    rotate([0,0,90])
    text("//ESP01-DSMR.local",size=3.5,halign=1,valign=1);
    translate([xmax-4,13,1])
   linear_extrude(height=2)
    rotate([0,0,90])
text("Slimme meter",size=5,halign=1,valign=1);  }
 

    
    
 

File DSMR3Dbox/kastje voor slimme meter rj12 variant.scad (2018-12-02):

xmax=40.7;
ymax=66;
zmax=23.5;
hoogte_rj12=15;
breedte_rj12=13.3;
//bodem_gat_x=38; 
//afstand tussen gaten voor de pcb bevestiging
bodem_gat_y=39.4;
bodem_gat_x=28.5;
diepte_gat=15; //schroefgat in hoekpunten
gat_top=5;  // afstand vanaf hoekpunt voor bovenplaat
// plaatsing halverwege tussen zijplaten
// het printed circuit moet precies tegen de wand komen
// aan de kant waar de RJ12 connector zit
// gat_bodem is de hartafstand van het gat in de printplaat
// tot de buitenkant (die op positie xmax zit
gat_bodem_x=5.6; 
// hart afstand van de gaten in het printed circuit
// in de x richting (kleinste afstand)
hart_afstand_x=28.5;
// hart afstand y richting van het pcb
hart_afstand_y=39.0;
gat_bodem_y=(ymax-bodem_gat_y)/2;
// dikte hoeksupport
hoek_support=8;
dikte=2.3;
dikte_pcb=1.7;
pcb_support=zmax-dikte_pcb-hoogte_rj12-0.5;
verlaging_hoek_support=dikte;
$fn=25;
//minkowski()

difference()
{union()
    // onderplaat
{cube([xmax,ymax,dikte]);
    // plaat voorkant
cube([dikte,ymax,zmax]);
   
       // plaat zijkant links
cube([xmax,dikte,zmax]);
    // plaat rechterzijkant
translate([xmax-dikte,0,0])
cube([dikte,ymax,zmax]);
     // ondersteuning rj12 female connector
    translate([xmax-14,ymax-gat_bodem_y-breedte_rj12-1,0])
    cube([8,17,zmax-hoogte_rj12-dikte_pcb-0.3]);
    // plaat achterkant
translate([0,ymax-dikte,0])
cube([xmax,dikte,zmax]);
    //hoekrondjes
translate([1.5,1.5,0])
cylinder(r=2,h=zmax);
translate([1.5,ymax-1.5,0])
cylinder(r=2,h=zmax);
translate([xmax-1.5,1.5,0])
cylinder(r=2,h=zmax);
translate([xmax-1.5,ymax-1.5,0])
cylinder(r=2,h=zmax);
    
    // stuk voor muurbevestiging
    translate([xmax/2-5,-10,0])
    cube([10,10,3]);
    translate([xmax/2-5,ymax,0])
    cube([10,10,3]);
 
// 4 cylinders voor bevestiging bovenplaat
translate([hoek_support/1.8,hoek_support/1.8,0]) 
cylinder(r=4.5,h=zmax);
translate([xmax-hoek_support/1.8,hoek_support/1.8,0])
cylinder(r=4.5,h=zmax);
translate([xmax-hoek_support/1.8,ymax-hoek_support/1.8,0])
cylinder(r=4.5,h=zmax);
translate([hoek_support/1.8,ymax-hoek_support/1.8,0])
cylinder(r=4.5,h=zmax);
// de drie ronde supports voor het pcb
translate([xmax-gat_bodem_x,gat_bodem_y,0]) 
cylinder(d=6,h=pcb_support);
translate([xmax-gat_bodem_x-hart_afstand_x,ymax-gat_bodem_y,0]) 
cylinder(d=6,h=pcb_support);
translate([xmax-gat_bodem_x-hart_afstand_x,gat_bodem_y,0]) 
cylinder(d=6,h=pcb_support);}
// dit zijn de stukken die eruit gaan
//hieronder het stuk uit de rechterzijwand
translate([xmax-dikte-1,ymax-gat_bodem_y-breedte_rj12+0.6,zmax-hoogte_rj12])
cube([4,breedte_rj12+0.2,hoogte_rj12]);
// de gaten in de muurbevestiging (zijpoootjes)
translate([xmax/2,-5,-1])
    cylinder(d=3,h=5);
    translate([xmax/2,ymax+5,-1])
    cylinder(d=3,h=5);
//gat in printed circuit board bevestiging
translate([xmax-gat_bodem_x,gat_bodem_y,dikte]) 
cylinder(d=3,h=7);
translate([xmax-gat_bodem_x-hart_afstand_x,ymax-gat_bodem_y,dikte]) 
cylinder(d=3,h=7);
translate([xmax-gat_bodem_x-hart_afstand_x,gat_bodem_y,dikte]) 
cylinder(d=3,h=7);
// gaten voor de bevestiging van de bovenplaat
translate([gat_top,gat_top,zmax-diepte_gat])
cylinder(d=3,h=diepte_gat+dikte+1);
translate([xmax-gat_top,gat_top,zmax-dikte-diepte_gat])
cylinder(d=3,h=diepte_gat+dikte+1);
translate([gat_top,ymax-gat_top,zmax-dikte-diepte_gat])
cylinder(d=3,h=diepte_gat+dikte+1);
translate([xmax-gat_top,ymax-gat_top,zmax-dikte-diepte_gat])
cylinder(d=3,h=diepte_gat+dikte+1);
// gaten voor uitstekende bevestigingsplug rj12 connector
translate([xmax-10.5,ymax-gat_bodem_y-10.5,dikte])
cylinder(d=4,h=10);
translate([xmax-10.5,ymax-gat_bodem_y-0.9,dikte])

cylinder(d=4,h=10);}

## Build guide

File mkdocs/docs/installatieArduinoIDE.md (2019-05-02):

## Installatie ArduinoIDE
Download en installeer de Arduino Integrated Development Environment (IDE) 
voor het Operating Systeem (OS) waar jouw DeskTop of LapTop computer (er 
zijn versies voor Windows, Linux en Mac) mee werkt.   
Je kunt de Software 
<a href="https://www.arduino.cc/en/Main/Software" target="_blank">
hier</a> downloaden.

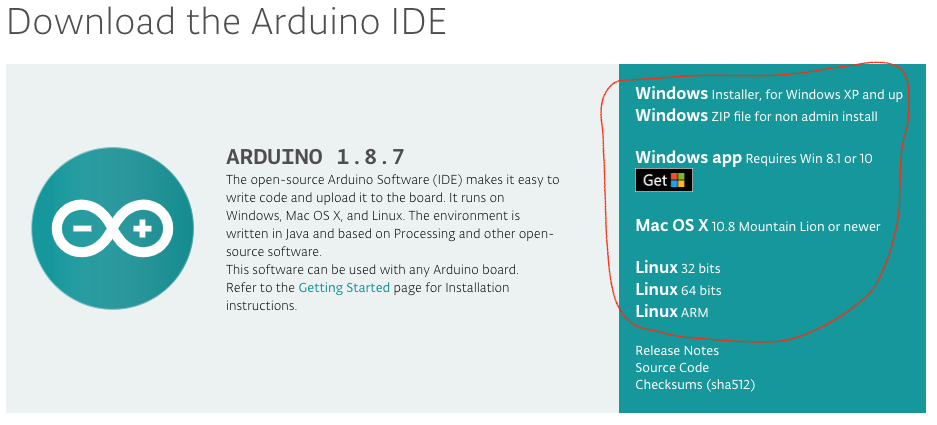
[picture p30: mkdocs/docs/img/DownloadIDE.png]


<div class="admonition note">
<p class="admonition-title">Let op!</p>
De DSMRlogger2HTTP firmware is getest met de ArduinoIDE v1.8.8 en v1.8.9
</div>

Na het downloaden moet je het ontvangen bestand uitpakken (unzip of untar) 
en installeren. Dat installeren is per OS anders maar staat duidelijk op de 
website van Arduino aangegeven. Eenmaal geïnstalleerd kun je direct met de 
Arduino IDE aan de slag.

Om de IDE met de ESP8266 microprocessor te kunnen gebruiken moeten we nog 
wat stappen uitvoeren.

<br>

---
<center style="font-size: 70%">[RJ12 connector]</center><br>
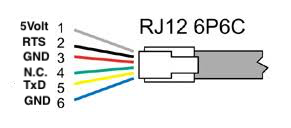
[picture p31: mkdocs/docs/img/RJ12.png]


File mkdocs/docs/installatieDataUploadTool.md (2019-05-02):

## Installatie Data Upload Tool
Eén van de mooie eigenschappen van de ESP8266 is dat er flash geheugen in zit. 
Flash geheugen is geheugen dat zijn inhoud ook zonder spanning behoud. 
Vergelijk het met een SD-kaart. Het flash geheugen is, afhankelijk van het 
bordje, 512kB tot 16MB(!) groot. Een deel van dit flash geheugen wordt gebruikt 
om jouw programma in op te slaan. Wat er over blijft kan als bestand-systeem 
worden ingericht (het zgn. *SPI Flash File Systeem* ‑SPIFFS‑).

Je kunt in je programma dit bestand-systeem niet alleen gebruiken om 
(bijvoorbeeld meet-) gegevens maar ook om de inhoud van
een web-pagina (`index.html`) of een configuratie-bestand in op te slaan.

Een *index.html* maakt dan natuurlijk onderdeel uit van je programma maar deze
ontwikkel je niet met de ArduinoIDE.

Om het `SPI Flash File Systeem` voor dit soort bestanden te 
kunnen gebruiken moet je een `plug-in` in je Arduino Projecten map installeren. 

De plug-in haal je 
<a href="https://github.com/esp8266/arduino-esp8266fs-plugin/releases/tag/0.4.0/" target="_blank">
hier</a>
vandaan.

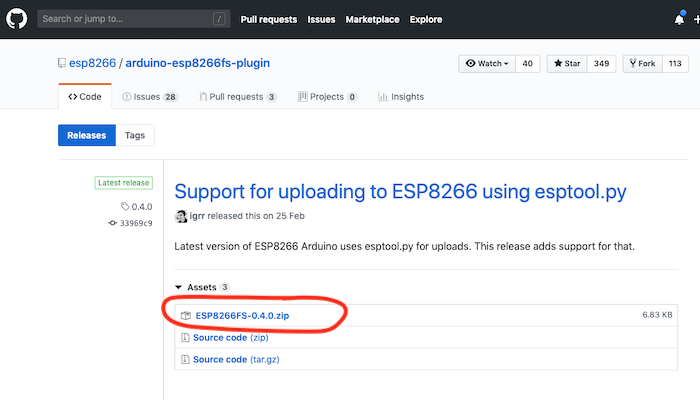
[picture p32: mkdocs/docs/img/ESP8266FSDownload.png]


Download vervolgens het `ESP8266FS-0.4.0.zip` bestand door er op te klikken.    

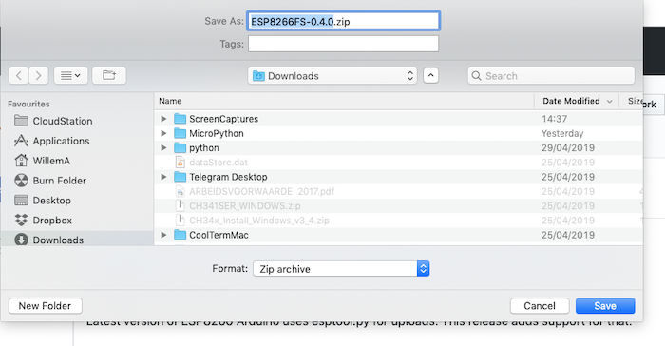
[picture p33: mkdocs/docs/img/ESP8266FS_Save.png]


En bewaar het bestand op een plek die voor jou handig is.

Ga nu naar je `Sketchbook Location` map en maak daarin een nieuwe map `tools` aan (als 
deze nog niet bestaat). Pak het zojuist ge-download-de zip bestand uit in deze 
`tools` map. Er wordt nu een aantal nieuwe mappen aangemaakt waar de plug-in wordt 
neergezet. Het pad ziet er ongeveer zo uit:

`<sketchbook location>/tools/ESP8266FS/tool/esp8266fs.jar`



Start de Arduino IDE opnieuw op.

Op de menu-balk zie je nu onder [`Tools`] een nieuwe optie: 
`ESP8266 Sketch Data Upload`.

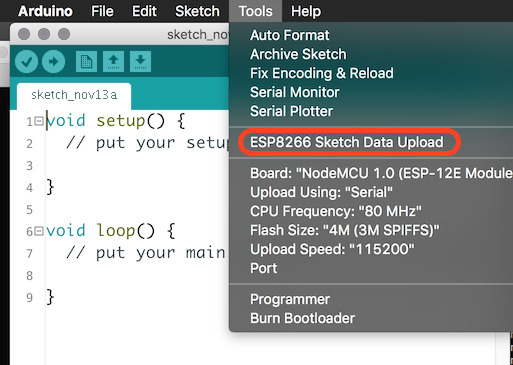
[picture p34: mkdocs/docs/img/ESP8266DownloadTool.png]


Als er onder de map van je Sketch óók een map `data` staat, dan kun je de 
bestanden die in deze `data`-map staan met het `Sketch Data Upload` tool naar
het SPIFFS van de ESP8266 flashen.

De bestands-tree van de DSMRlogger2HTTP firmware ziet er zo uit:
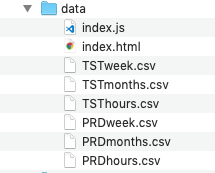
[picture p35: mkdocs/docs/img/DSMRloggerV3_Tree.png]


Het `ESP8266 Sketch Data Upload` tool zal alle bestanden dit in de `data`-map zitten
naar het SPIFFS van de aangesloten ESP8266 uploaden.

Ga naar: [`tools`] -> [`ESP8266 Sketch Data Upload`] 

Randvoorwaarde is natuurlijk dat het SPIFFS groot genoeg is!
In de selectie van je board moet je, 
behalve het juiste type board ook aangeven hoeveel ruimte van je Flash geheugen je 
wilt gebruiken voor het bestand-systeem (vóórdat je je programma naar de ESP8266 
upload!). 

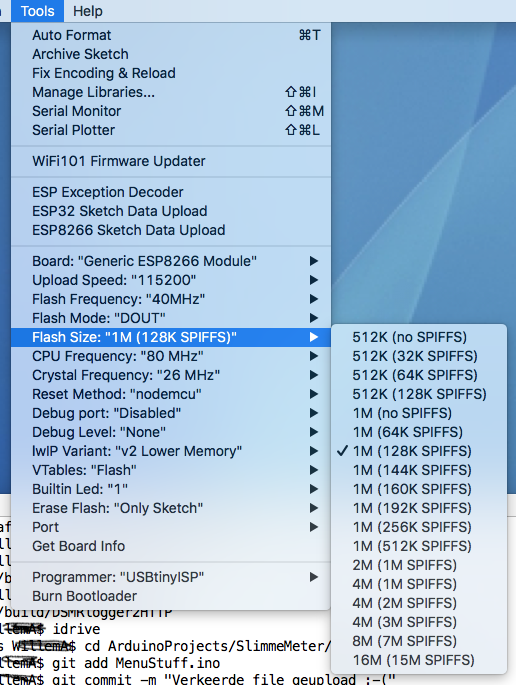
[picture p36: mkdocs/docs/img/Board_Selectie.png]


Normaliter zou je dit zo groot mogelijk willen maken, maar als je 
“Over The Air” programma’s op je ESP8266 wilt zetten (dus zonder fysieke verbinding 
maar via WiFi) dan moet je er rekening mee houden dat je twee maal de grootte van je 
programma nodig hebt om dit te kunnen doen. Wat er overblijft kun je als 
bestand-systeem gebruiken.

<br>

---
<center  style="font-size: 70%">[ChartFinancieel]</center><br>
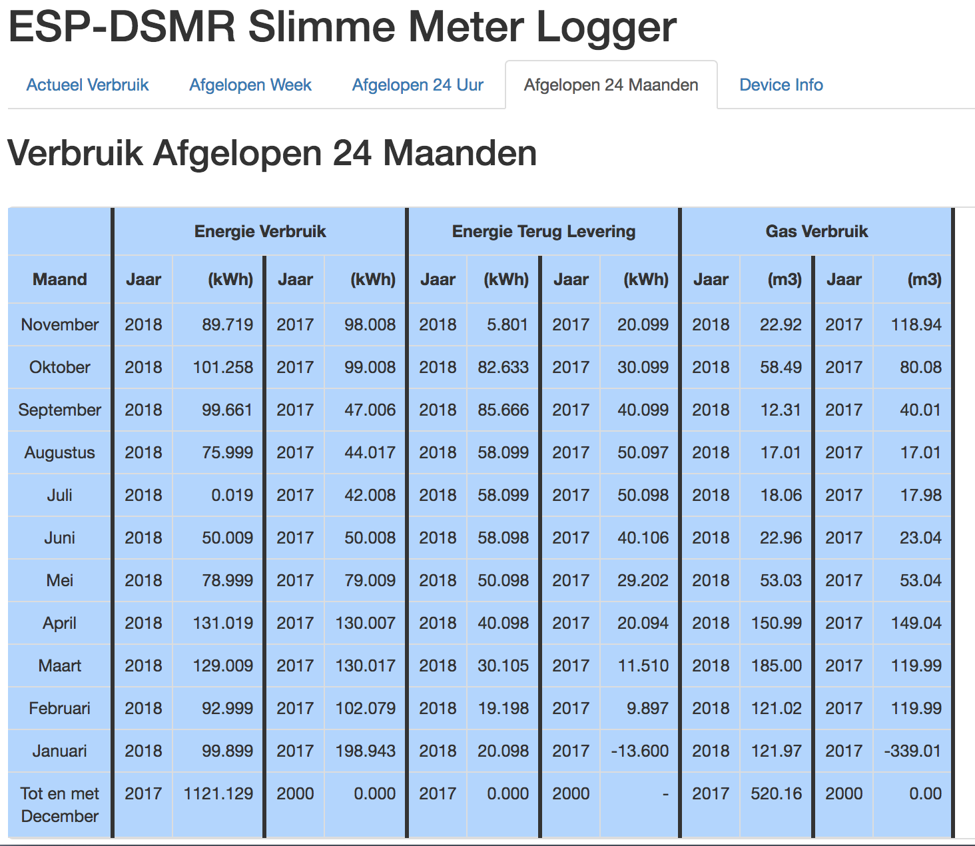
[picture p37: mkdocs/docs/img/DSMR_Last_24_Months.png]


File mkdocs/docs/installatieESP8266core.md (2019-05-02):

## Installatie ESP8266 core
In de Arduino IDE moet bij “Instellingen” de volgende URL worden ingevoerd 
achter “*Additional Boards Manager URL’s:*” (zie rood omlijnde kader)

`http://arduino.esp8266.com/stable/package_esp8266com_index.json`

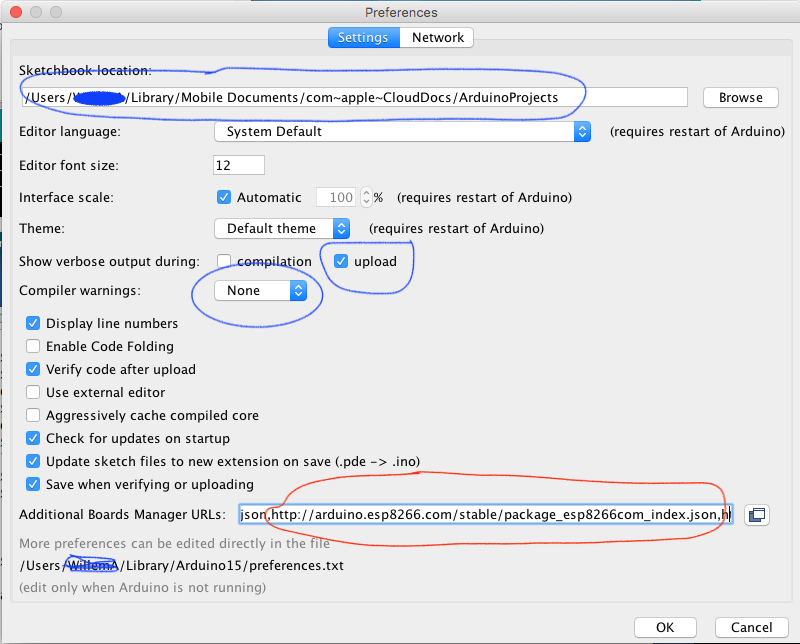
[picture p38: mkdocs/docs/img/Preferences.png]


Lees vooral de uitleg in het 
<a href="https://github.com/esp8266/Arduino/blob/master/README.md" target="_blank">
`README.md`</a>
bestand en de uitgebreide 
<a href="https://arduino-esp8266.readthedocs.io/en/2.5.0/" target="_blank">
`documentatie`</a>
op hun website!

Er kunnen meer additional board manager URL’s worden ingevuld. Je moet ze dan 
achter elkaar zetten en scheiden door een komma (**,**).

Eventueel kun je ook het pad waar je projecten staan (de `Sketchbook Location`) 
aanpassen. Standaard verwijst deze naar je `Documenten` map:

`C:\Users\<LogInNaam>\Documents\arduino\`

.. en dat is een prima plek!

De andere instellingen kun je naar behoefte aanpassen. Hierboven staan de 
instellingen die ik prettig vind. 

Na het maken van aanpassingen klik je op [OK].

Ga nu via de ArduinoIDE menu-balk naar
[`Tools`] -> [`Board`] -> [`Boards Manager`]. 

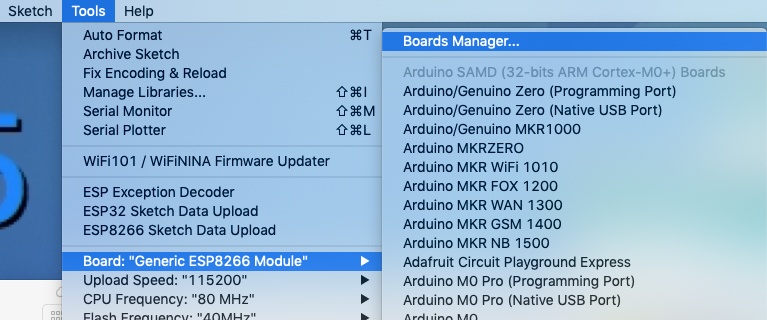
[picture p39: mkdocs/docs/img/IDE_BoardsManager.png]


Voer bij filter “esp8266” in. 

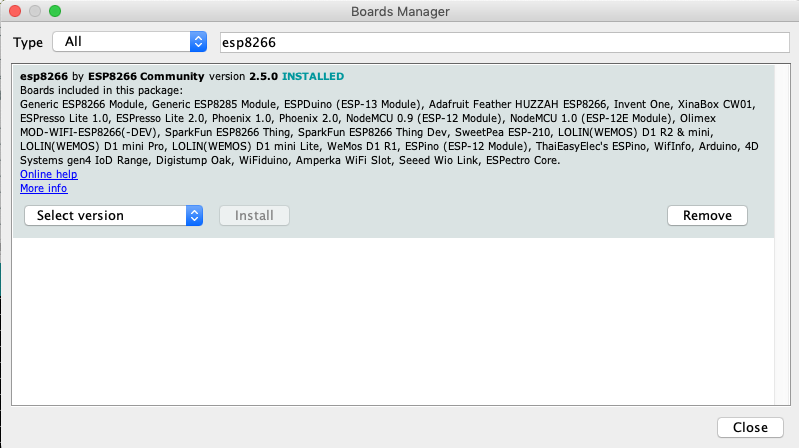
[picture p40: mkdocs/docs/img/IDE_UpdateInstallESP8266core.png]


Selecteer de versie die je wilt gaan gebruiken en klik op [`Install`].

<div class="admonition note">
<p class="admonition-title">Let op!</p>
De DSMRlogger2HTTP firmware is getest met <b>versie 2.4.0</b> en <b>versie 2.5.0</b>.
</div>

<br>

---
<center  style="font-size: 70%">[ScreenShot DSMR Uur]</center><br>
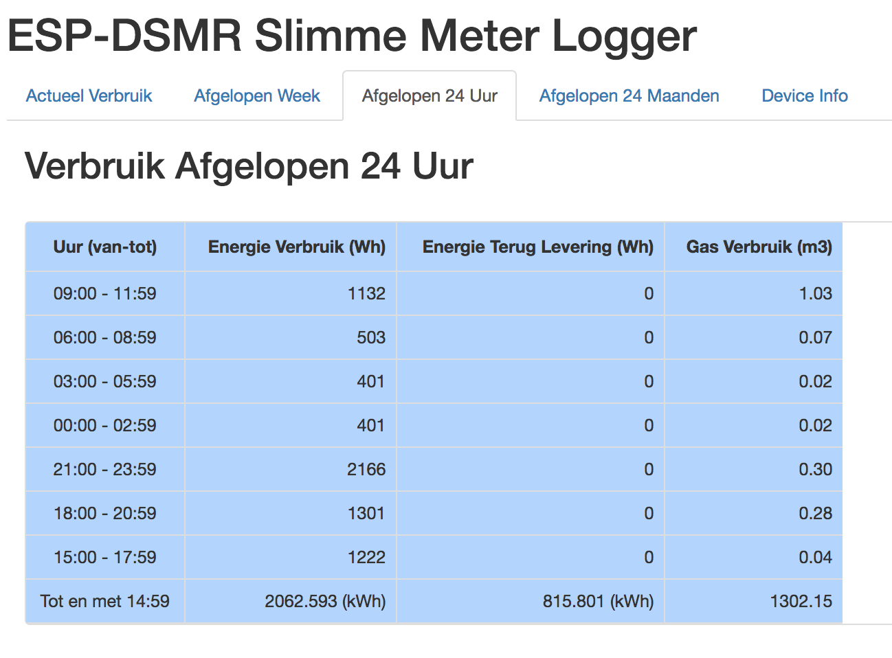
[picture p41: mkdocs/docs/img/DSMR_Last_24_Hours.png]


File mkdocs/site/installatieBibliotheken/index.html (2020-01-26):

- Docs »
- Firmware »
- Installeren Bibliotheken

## Installatie Bibliotheken

hier (https://www.arduino.cc/en/guide/libraries) vind je de officiële instructies voor het installeren van bibliotheken met de ArduinoIDE.

Nu je een ArduinoIDE hebt waarmee je ESP8266’s kunt programmeren (flashen) zul je ontdekken dat er door briljante mensen software is ontwikkeld die je kunt gebruiken om complexe projecten te realiseren, zonder dat je zelf het wiel hoeft uit te vinden.

Deze software wordt veelal in de vorm van een bibliotheek aangeboden en je hoeft zo’n bibliotheek alleen maar te installeren om er gebruik van te kunnen maken.

Bijvoorbeeld een bibliotheek om je ESP8266 van een telnet server te voorzien (met een telnet server kun je via een telnet-client op je DeskTop of LapTop inloggen op je ESP8266). Er blijken hier een aantal bibliotheken voor te bestaan.

Als voorbeeld nemen we TelnetStream van Juraj Andrassy. Na wat Googelen vinden we de software op deze https://github.com/jandrassy/TelnetStream/ github pagina.

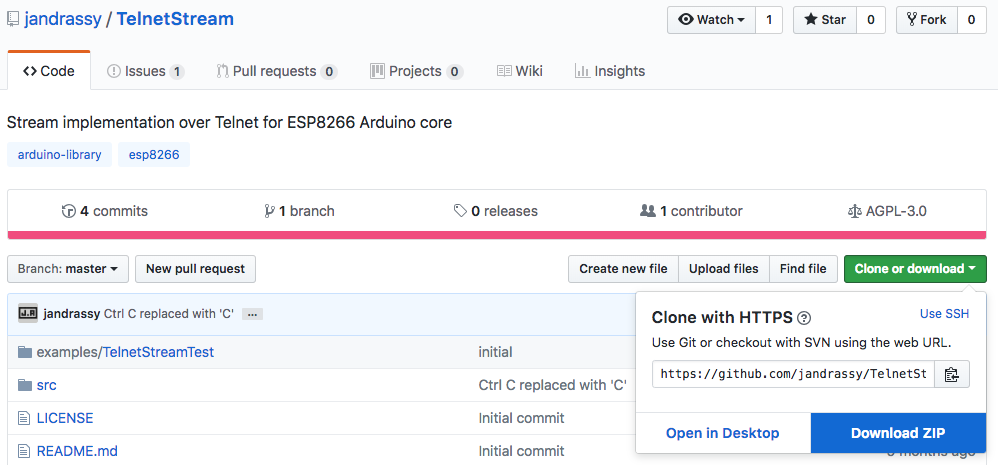
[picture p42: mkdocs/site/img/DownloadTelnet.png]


Om de bibliotheek te installeren klik je op de groene [Clone or Download] knop en selecteer je [Download ZIP].

Onthou waar je het zip-file bewaard!

Ga nu naar de ArduinoIDE en selecteer:

[Sketch] => [Include Library] => [Add .ZIP Library]

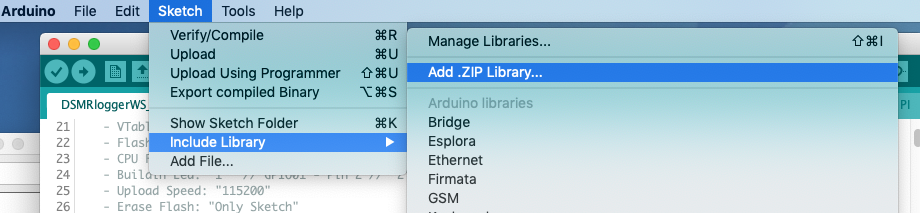
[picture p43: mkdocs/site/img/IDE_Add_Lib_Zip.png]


Er verschijnt een selectie window waar je het zojuist ge-download-de bestand selecteert.

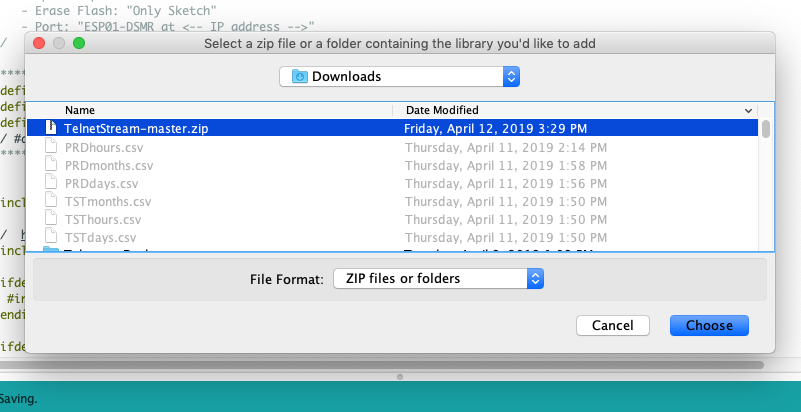
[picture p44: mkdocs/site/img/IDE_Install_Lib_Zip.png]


Klik op [Choose].

De bibliotheek is nu geïnstalleerd en klaar om gebruikt te worden. De meeste bibliotheken komen met een aantal voorbeeld programma’s waarmee je kunt leren hoe je de bibliotheek kunt gebruiken.

Juraj Andrassy is erg summier met zijn uitleg maar gelukkig is er een map met voorbeelden (nou ja, één voorbeeld).

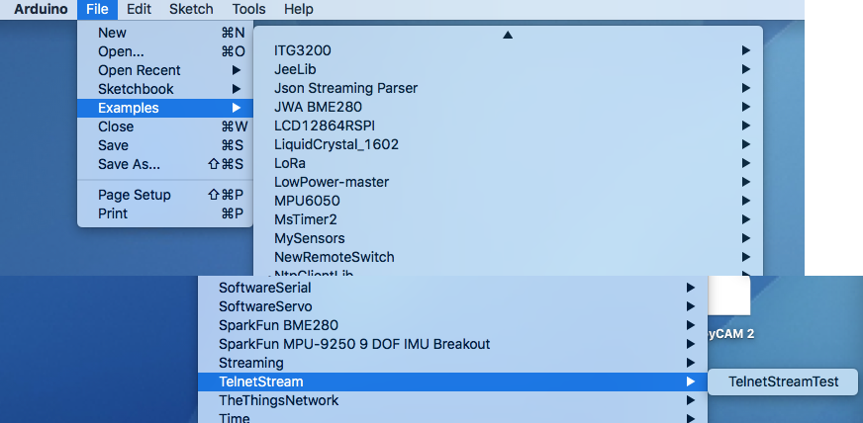
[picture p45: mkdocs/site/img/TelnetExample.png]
 (sorry, het plaatje is een beetje verknipt)

Klik je nu op [TelnetStreamTest] dan wordt dit voorbeeld programma in de ArduinoIDE geladen.

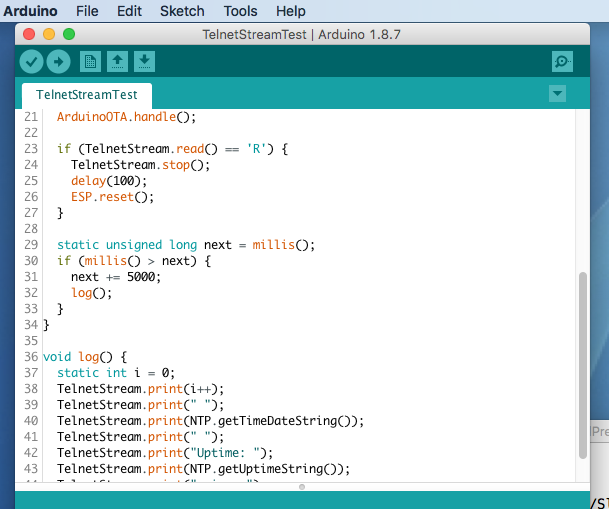
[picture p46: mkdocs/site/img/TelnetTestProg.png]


Installeer op dezelfde manier de bibliotheken die in het vorige hoofdstuk zijn genoemd.

[DSMR Device Info]
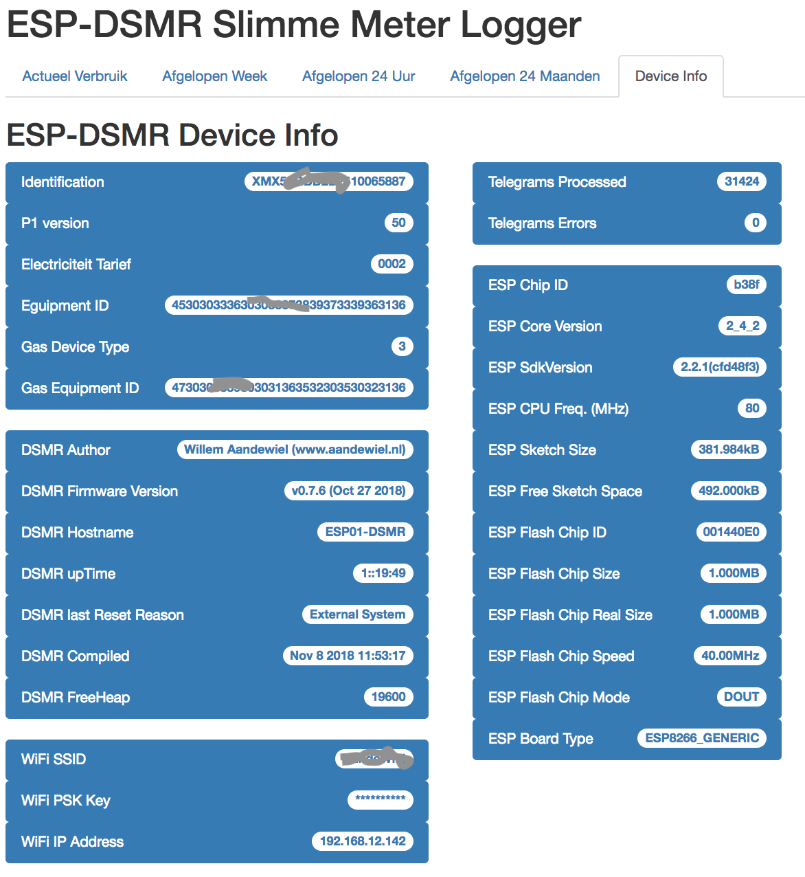
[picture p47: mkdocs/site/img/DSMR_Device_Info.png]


Next Previous

copyright © 2018 - 2019 Willem Aandewiel

Built with MkDocs (http://www.mkdocs.org) using a theme (https://github.com/snide/sphinx_rtd_theme) provided by Read the Docs (https://readthedocs.org).

« Previous Next »

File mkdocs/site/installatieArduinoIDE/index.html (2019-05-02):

- Docs »
- Voorbereiding »
- ArduinoIDE

## Installatie ArduinoIDE

Download en installeer de Arduino Integrated Development Environment (IDE) voor het Operating Systeem (OS) waar jouw DeskTop of LapTop computer (er zijn versies voor Windows, Linux en Mac) mee werkt.
Je kunt de Software hier (https://www.arduino.cc/en/Main/Software) downloaden.



Let op!

De DSMRlogger2HTTP firmware is getest met de ArduinoIDE v1.8.8 en v1.8.9

Na het downloaden moet je het ontvangen bestand uitpakken (unzip of untar) en installeren. Dat installeren is per OS anders maar staat duidelijk op de website van Arduino aangegeven. Eenmaal geïnstalleerd kun je direct met de Arduino IDE aan de slag.

Om de IDE met de ESP8266 microprocessor te kunnen gebruiken moeten we nog wat stappen uitvoeren.

[RJ12 connector]


Next Previous

copyright © 2018 - 2019 Willem Aandewiel

Built with MkDocs (http://www.mkdocs.org) using a theme (https://github.com/snide/sphinx_rtd_theme) provided by Read the Docs (https://readthedocs.org).

« Previous Next »

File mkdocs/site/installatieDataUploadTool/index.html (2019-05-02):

- Docs »
- Voorbereiding »
- Data Upload Tool

## Installatie Data Upload Tool

Eén van de mooie eigenschappen van de ESP8266 is dat er flash geheugen in zit. Flash geheugen is geheugen dat zijn inhoud ook zonder spanning behoud. Vergelijk het met een SD-kaart. Het flash geheugen is, afhankelijk van het bordje, 512kB tot 16MB(!) groot. Een deel van dit flash geheugen wordt gebruikt om jouw programma in op te slaan. Wat er over blijft kan als bestand-systeem worden ingericht (het zgn. SPI Flash File Systeem ‑SPIFFS‑).

Je kunt in je programma dit bestand-systeem niet alleen gebruiken om (bijvoorbeeld meet-) gegevens maar ook om de inhoud van een web-pagina (index.html) of een configuratie-bestand in op te slaan.

Een index.html maakt dan natuurlijk onderdeel uit van je programma maar deze ontwikkel je niet met de ArduinoIDE.

Om het SPI Flash File Systeem voor dit soort bestanden te kunnen gebruiken moet je een plug-in in je Arduino Projecten map installeren.

De plug-in haal je hier (https://github.com/esp8266/arduino-esp8266fs-plugin/releases/tag/0.4.0/) vandaan.



Download vervolgens het ESP8266FS-0.4.0.zip bestand door er op te klikken.



En bewaar het bestand op een plek die voor jou handig is.

Ga nu naar je Sketchbook Location map en maak daarin een nieuwe map tools aan (als deze nog niet bestaat). Pak het zojuist ge-download-de zip bestand uit in deze tools map. Er wordt nu een aantal nieuwe mappen aangemaakt waar de plug-in wordt neergezet. Het pad ziet er ongeveer zo uit:

<sketchbook location>/tools/ESP8266FS/tool/esp8266fs.jar



Start de Arduino IDE opnieuw op.

Op de menu-balk zie je nu onder [Tools] een nieuwe optie: ESP8266 Sketch Data Upload.



Als er onder de map van je Sketch óók een map data staat, dan kun je de bestanden die in deze data-map staan met het Sketch Data Upload tool naar het SPIFFS van de ESP8266 flashen.

De bestands-tree van de DSMRlogger2HTTP firmware ziet er zo uit: 

Het ESP8266 Sketch Data Upload tool zal alle bestanden dit in de data-map zitten naar het SPIFFS van de aangesloten ESP8266 uploaden.

Ga naar: [tools] -> [ESP8266 Sketch Data Upload]

Randvoorwaarde is natuurlijk dat het SPIFFS groot genoeg is! In de selectie van je board moet je, behalve het juiste type board ook aangeven hoeveel ruimte van je Flash geheugen je wilt gebruiken voor het bestand-systeem (vóórdat je je programma naar de ESP8266 upload!).



Normaliter zou je dit zo groot mogelijk willen maken, maar als je “Over The Air” programma’s op je ESP8266 wilt zetten (dus zonder fysieke verbinding maar via WiFi) dan moet je er rekening mee houden dat je twee maal de grootte van je programma nodig hebt om dit te kunnen doen. Wat er overblijft kun je als bestand-systeem gebruiken.

[ChartFinancieel]


Next Previous

copyright © 2018 - 2019 Willem Aandewiel

Built with MkDocs (http://www.mkdocs.org) using a theme (https://github.com/snide/sphinx_rtd_theme) provided by Read the Docs (https://readthedocs.org).

« Previous Next »

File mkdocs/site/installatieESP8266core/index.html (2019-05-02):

- Docs »
- Voorbereiding »
- ESP8266 Core

## Installatie ESP8266 core

In de Arduino IDE moet bij “Instellingen” de volgende URL worden ingevoerd achter “Additional Boards Manager URL’s:” (zie rood omlijnde kader)

http://arduino.esp8266.com/stable/package_esp8266com_index.json



Lees vooral de uitleg in het README.md (https://github.com/esp8266/Arduino/blob/master/README.md) bestand en de uitgebreide documentatie (https://arduino-esp8266.readthedocs.io/en/2.5.0/) op hun website!

Er kunnen meer additional board manager URL’s worden ingevuld. Je moet ze dan achter elkaar zetten en scheiden door een komma (,).

Eventueel kun je ook het pad waar je projecten staan (de Sketchbook Location) aanpassen. Standaard verwijst deze naar je Documenten map:

C:\Users\<LogInNaam>\Documents\arduino\

.. en dat is een prima plek!

De andere instellingen kun je naar behoefte aanpassen. Hierboven staan de instellingen die ik prettig vind.

Na het maken van aanpassingen klik je op [OK].

Ga nu via de ArduinoIDE menu-balk naar [Tools] -> [Board] -> [Boards Manager].



Voer bij filter “esp8266” in.



Selecteer de versie die je wilt gaan gebruiken en klik op [Install].

Let op!

De DSMRlogger2HTTP firmware is getest met versie 2.4.0 en versie 2.5.0.

[ScreenShot DSMR Uur]


Next Previous

copyright © 2018 - 2019 Willem Aandewiel

Built with MkDocs (http://www.mkdocs.org) using a theme (https://github.com/snide/sphinx_rtd_theme) provided by Read the Docs (https://readthedocs.org).

« Previous Next »

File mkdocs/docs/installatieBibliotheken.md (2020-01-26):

## Installatie Bibliotheken

<a href="https://www.arduino.cc/en/guide/libraries" target="_blank">
hier</a>
vind je de officiële instructies
voor het installeren van bibliotheken met de ArduinoIDE.

Nu je een ArduinoIDE hebt waarmee je ESP8266’s kunt programmeren (flashen) zul je 
ontdekken dat er door briljante mensen software is ontwikkeld die je kunt 
gebruiken om complexe projecten te realiseren, zonder dat je zelf het wiel 
hoeft uit te vinden.

Deze software wordt veelal in de vorm van een bibliotheek aangeboden en je 
hoeft zo’n bibliotheek alleen maar te installeren om er gebruik van te kunnen maken.

Bijvoorbeeld een bibliotheek om je ESP8266 van een telnet server te voorzien (met 
een telnet server kun je via een telnet-client op je DeskTop of LapTop inloggen op 
je ESP8266). Er blijken hier een aantal bibliotheken voor te bestaan. 

Als voorbeeld nemen we *TelnetStream* van *Juraj Andrassy*. Na wat Googelen vinden we de 
software op deze
<a href="https://github.com/jandrassy/TelnetStream/" target="_blank">
https://github.com/jandrassy/TelnetStream/</a>
github pagina. 



Om de bibliotheek te installeren klik je op de groene 
<span style="background: green; color: white;">[Clone or Download]</span>
knop en selecteer je 
<span style="background: blue; color: white;">[Download ZIP]</span>.

Onthou waar je het zip-file bewaard!

Ga nu naar de ArduinoIDE en selecteer:

[`Sketch`] => [`Include Library`] => [`Add .ZIP Library`]



Er verschijnt een selectie window waar je het zojuist ge-download-de bestand selecteert.



Klik op <span style="background: blue; color: white;">[Choose]</span>.

De bibliotheek is nu geïnstalleerd en klaar om gebruikt te worden. De meeste 
bibliotheken komen met een aantal voorbeeld programma’s waarmee je kunt leren 
hoe je de bibliotheek kunt gebruiken.

*Juraj Andrassy* is erg summier met zijn uitleg maar gelukkig is 
er een map met voorbeelden (nou ja, één voorbeeld). 


(sorry, het plaatje is een beetje verknipt)

Klik je nu op [`TelnetStreamTest`] dan wordt dit voorbeeld programma 
in de ArduinoIDE geladen.



---
Installeer op dezelfde manier de bibliotheken die in het [vorige hoofdstuk](benodigdeBibliotheken.md)
zijn genoemd.

<br>

---
<center style="font-size: 70%">[DSMR Device Info]</center><br>


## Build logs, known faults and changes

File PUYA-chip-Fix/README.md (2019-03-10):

***Achter de Engelse tekst staat dezelfde tekst in het Nederlands***

**\*\*\* With the ESP8266 core 2.5.0 the PUYA patch should not be necessery anymore \*\*\***

There are a lot of ESP-01 board available now which have a Flash Chip from PUYA.
This Flash chip is not compatible with the normaly used Flash chip.

If you flash the DSMRlogger2HTTP firmware to boards with this chip everything looks alright but ...
as soon as you try to read data from the SPIFFS filesystem everything goes wrong.

There are a lot of treads about this subject. Fore instance:

```
     https://github.com/letscontrolit/ESPEasy/issues/748
```

but there are more. Luckely @igrr has fixed the SPIFFS read problem with the PUYA flash chip!

```
     See: https://github.com/esp8266/Arduino/issues/4061
```

I have provided a patched version of the file ```Esp.cpp```. This file will work with all types of Flash
chips so just do the following:

### Install patched version Esp.cpp
Find the ```esp8266/hardware/esp8266/2.4.2/cores/esp8266``` map on your computer. On my iMac it is:

```   .../Arduino15/packages/esp8266/hardware/esp8266/2.4.2/cores/esp8266 ```

Go to this directory

``` cd .../Arduino15/packages/esp8266/hardware/esp8266/2.4.2/cores/esp8266 ```

and check whether there is a file called ```Esp.cpp```

now **rename** the file ```Esp.cpp``` to something like ```Esp.cpp.org``` so you can alway's return to this version.

Than, copy the file ```Esp.cpp``` from this repository to this directory

```copy <where-ever-you-downloaded-this>/Esp.cpp  . ``` (there is a &lt;dot&gt; at the end!)

or

```cp <where-ever-you-downloaded-this>/Esp.cpp  . ``` 

And now restart the Arduino-IDE and your good to program (also) boards with a PUYA Flash chip!

Once the ```Esp.cpp``` file is replaced, restart the IDE and flash your sketch using 
the "**Tools -> Erase Flash -> All Flash Contents**" option. 
After it's done flashing, go to "**Tools -> ESP8266 Sketch Data Upload**". This will upload all the 
files in the "**data**" subfolder of your sketch folder.

## Nederlands

**\*\*\* Met de ESP8266 core 2.5.0 zou de PUYA patch niet meer nodig moeten zijn \*\*\***

Er zijn een heleboel ESP-01 bordjes in omloop die een Flash chip van PUYA hebben.
Deze Flash chip is niet compatibel met de gewoonlijk aanwezige Flash chips.

Als je de DSMRlogger2HTTP firmware naar een borje met deze PUYA chip upload, dan lijkt alles in orde maar ...
zodra je van het SPIFFS bestandssysteem probeert te lezen gaat alles fout!

Er is een hoop discussie over dit onderwerp. Bijvoorbeeld:
```
     https://github.com/letscontrolit/ESPEasy/issues/748
     https://github.com/esp8266/Arduino/issues/4061
```
maar er zijn er meer. Gelukkig heeft @igrr een oplossing voor het SPIFFS lees probleem voor de PUYA chips!
```
     Zie: https://github.com/esp8266/Arduino/issues/4061
```
Ik heb in deze repository een gepatched bestand Esp.cpp opgenomen. Deze versie van Esp.cpp werkt met 
alle bekende versies Flash chips (dus niet alleen voor de PUYA chip!).

### Installeren van het gepatchte Esp.cpp bestand
Zoek de ```esp8266/hardware/esp8266/2.4.2/cores/esp8266``` directory op jouw computer. Op mijn iMac staat die hier:
```
   .../Arduino15/packages/esp8266/hardware/esp8266/2.4.2/cores/esp8266 
```
Ga naar deze directory
```
   cd .../Arduino15/packages/esp8266/hardware/esp8266/2.4.2/cores/esp8266 
```
Controleer of in deze map een bestand ```Esp.cpp``` staat!

vervolgens **rename** je dit bestand ```Esp.cpp``` in iets als ```Esp.cpp.org``` zodat 
je altijd naar deze versie terug kunt.

Daarna kopieer je het bestand ```Esp.cpp``` uit deze repository naar deze directory:

```copy <where-ever-you-downloaded-this>/Esp.cpp . ``` (er staat een &lt;punt&gt; aan het eind van de opdracht)

of:

```cp <where-ever-you-downloaded-this>/Esp.cpp . ``` 

Nu de Arduino-IDE opnieuw opstarten en je kunt (ook) bordjes met een PUYA Flash chip flashen!

Nu ```Esp.cpp``` bestand is vervangen door het ge-patch-te ```Esp.cpp``` bestand, moet je de IDE herstarten en beginnen
met het flash van een sketch met de "**Tools -> Erase Flash -> All Flash Contents**" optie! 
Als het flashen klaar is, kun je met "**Tools -> ESP8266 Sketch Data Upload**" de bestanden in de "**data**" sub-map van je sketch map naar de ESP-01 overzetten.

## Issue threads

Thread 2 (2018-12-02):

Geen gasstanden

jicho, 2018-12-02:
Hi,

Wat kan er aan de hand zijn als ik geen gasmetingen binnen krijg? Stroom werkt als een trein, gas metingen blijven op 0 staan... De slimme meter geeft wel de gas stand door en m'n vorige aansluiting i.c.m. een USB kabel met een RasPi gaf ook netjes gasmetingen door...

Dit is wat getActual.json retour geeft:

```
{
   "Timestamp":"181202135402W",
   "Energy_Delivered":"1346.791",
   "Energy_Returned":"0.000",
   "Gas_Delivered":"0.00",
   "Energy_Delivered_Tariff1":"616.279",
   "Energy_Delivered_Tariff2":"730.512",
   "Energy_Returned_Tariff1":"0.000",
   "Energy_Returned_Tariff2":"0.000",
   "Power_Delivered":"0.119",
   "Power_Returned":"0.000",
   "Voltage_l1":"228.5",
   "Current_l1":"0",
   "Voltage_l2":"0.0",
   "Current_l2":"0",
   "Voltage_l3":"0.0",
   "Current_l3":"0",
   "Power_Delivered_l1":"119",
   "Power_Returned_l1":"0",
   "Power_Delivered_l2":"0",
   "Power_Returned_l2":"0",
   "Power_Delivered_l3":"0",
   "Power_Returned_l3":"0"
}
```

Mocht het handig zijn mijn device aldus device info:
ISK5\2M550E-1012

P1 version aldus device info:
50

Gebruikte firmware:
v0.7.6 (Oct 27 2018)

Gebruikte versie arduino-dsmr library:
De laatste die op de Git staat (versie van gisteren)

Mijn kennis is te beperkt om de boel te debuggen, mocht iets na moeten kijken, dan wil ik dat met alle liefde doen :)

Aanvulling:
Bij equipment ID staat momenteel onder device info "unknown". Beetje vreemd als je het mij vraagt...

jicho, 2018-12-02:
Oh jee, de software zit nog uitgebreider in elkaar dan ik al dacht! Je kunt via Telnet (en wat geduld) een telegram afvangen. 't Is me gelukt om een telegram af te vangen:

```
/ISK5\2M550E-1012                                                       
                                                                        
1-3:0.2.8(50)                                                           
0-0:1.0.0(181202172628W)                                                
0-0:96.1.1(453030*************************323137)                          
1-0:1.8.1(000616.846*kWh)                                               
1-0:1.8.2(000730.512*kWh)                                               
1-0:2.8.1(000000.000*kWh)                                               
1-0:2.8.2(000000.000*kWh)                                               
0-0:96.14.0(0001)                                                       
1-0:1.7.0(00.089*kW)                                                    
1-0:2.7.0(00.000*kW)                                                    
0-0:96.7.21(00009)                                                      
0-0:96.7.9(00004)                                                       
1-0:99.97.0(2)(0-0:96.7.19)(180116115413W)(0000002996*s)(181103104217W)(00000042
71*s)                                                                   
1-0:32.32.0(00009)                                                      
1-0:32.36.0(00001)                                                      
0-0:96.13.0()                                                           
1-0:32.7.0(225.4*V)                                                     
1-0:31.7.0(000*A)                                                       
1-0:21.7.0(00.089*kW)                                                   
1-0:22.7.0(00.000*kW)                                                   
0-2:24.1.0(003)                                                         
0-2:96.1.0(4730303********************333137)                          
0-2:24.2.1(181202172503W)(00282.873*m3)                                 
!0D03
```

'k Kan me vergissen, maar volgens mij is er een gasmeterstand beschikbaar en ook is er een equipment ID beschikbaar. Zou dus, voor mijn gevoel, niet op "unknown" moeten staan.

mrWheel, 2018-12-02:
Ik zou zeggen dat dit:

```
0-2:96.1.0(4730303********************333137)                          
0-2:24.2.1(181202172503W)(00282.873*m3)

```
De gas info is. Mijn meter is ook 5.0 maar wellicht dat jouw gas-meter andere info stuurt ...

De dsmr library parsed:

```
"0-1:96.1.0(0000000000000000000000000000000000)\r\n"
"0-1:24.2.1(150117180000W)(00473.789*m3)\r\n"

```
Ik denk dat je de bibliotheek moet aanpassen (of contact opnemen met Matthijs Kooijman!

jicho, 2018-12-02:
Thanks, 'k ga kijken wat Matthijs Kooijman zijn reactie is (https://github.com/matthijskooijman/arduino-dsmr/issues/19).

Als ik mijn versie vergelijk met het voorbeeld hierboven, dan lijkt het er op dat het probleem zit in het beginnende gedeelte (0-2) in mijn telegram t.o.v. van de 0-1 in het voorbeeld.

Maar goed, laten we maar even wachten op de expert.

jicho, 2018-12-03:
Het probleem zit hem in het feit dat mijn gasmeter (is vervangen) nu op MBUS 2 zit i.p.v. 1. De paarse library gaat er vanuit dat de gasmeter op MBUS 1 aanwezig is...

Ik kom dus niet om een handmatige aanpassing van de library heen :(

jicho, 2018-12-03:
Kleine aanvulling voor iemand anders die dit leest en hetzelfde probleem heeft...

Het aanpassen de ID's in deze twee constanten in de arduino-dsmr library:
```
const uint8_t GAS_MBUS_ID = 1;
const uint8_t WATER_MBUS_ID = 2;
```

is de oplossing. 'k Heb gasmetingen :)

Closed 2018-12-03.

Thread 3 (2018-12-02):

Metingen afgelopen 4 uur

jicho, 2018-12-02:
Hi,

Waarom zijn is het totaal van de afgelopen 24 uur in kWh en is het energie verbruik in de tijdseenheden erboven in Wh?

Is dan niet een beetje lastig? Je moet nu dubbel kijken om het overzicht goed te kunnen interpreteren.

mrWheel, 2018-12-02:
In een korte periode verbruik je niet zoveel energie. Vandaar de kleinere eenheid.

Closed 2018-12-02.

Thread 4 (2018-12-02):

Eerste stroomverbruik registratie doet iets vreemds

jicho, 2018-12-02:
Hi,

Gisteren heb ik de logger in gebruik genomen i.c.m. het bordje van Opencircuit. Werkt goed, alleen de eerste registratie is een beetje (denk ik) vreemd.

In het "verbruik van afgelopen week"  krijg ik op zaterdag niet het dagtotaal van de zaterdag te zien, maar het totaal van T1 + T2 vanaf het moment dat de meter actief is. Zou de logica niet zo moeten werken dat als voor het eerst gaat meten je geen totalen toont tot dus toe?

Of... heb ik tijdens de installatie van de software iets over het hoofd gezien? :)

mrWheel, 2018-12-02:
Nee, helemaal volgens design. Wat wordt opgeslagen is de meterstand. Om het verbruik in een periode te bepalen wordt de vorige meterstand van de daarná gemeten stand afgetrokken. Als de eerste stand "0" is ... krijg je een vreemde waarde die uiteindelijk uit het overzicht wegloopt.
Als je daar niet op kunt wachten kan je de tabel via de maintenance page downloaden, aanpassen en weer uploaden (dan wel via telnet meteen op "G" klikken om de bestanden in het geheugen te laden!

Closed 2018-12-02.

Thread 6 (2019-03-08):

Call of overloaded 'String(IPAddress)' is ambiguous

softstones, 2019-03-08:
Arduino IDE v1.8.8 geeft een error tijdens het compileren (Call of overloaded 'String(IPAddress)' is ambiguous). Het betreft regel 21 in de sketch 'WiFi Stuff'. Het commenten van de betreffende regel zorgde ervoor dat de ESP8266 geen verbinding maakte met het netwerk.

Direct de .bin flashen met esptool werkte wel.

mrWheel, 2019-03-10:
@softstones
Ik heb een nieuwe versie (v0.7.7) ge-upload die geschikt is voor de Arduino IDE 1.8.8 én ESP8266 core versie 2.5.0

Closed 2019-03-10.

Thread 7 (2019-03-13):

Buildin led must "2" for ESP-01S

DannyvdSluijs, 2019-03-13:
The ESP-01S board that is provided by OpenCircuit as a replacement will not work with the current settings. After some tinkering I found when configuring the building led to `2` it works without the need to change anything.

I believe it would be wise to add this detail to the read-me as well.

dingetje, 2019-03-14:
@DannyvdSluijs thanks!

mrWheel, 2019-03-24:
@DannyvdSluijs thanks indeed! And I will.

Closed 2019-03-24.

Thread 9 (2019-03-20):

Working on an alternative UI

DannyvdSluijs, 2019-03-20:
Hello,

I wanted to reach out to you @mrWheel. Since there is no obvious social media contact I thought I would give it a go here.

I'm liking the project very much as you made it possible to have a cheap alternative to the current solutions offered by the power companies. However I would like to see the data in a more informative way, so I decided to get working on this. See some images of my initial draft at https://github.com/DannyvdSluijs/dsmr-ui. In order to make it work on the ESP8266 I'm getting as much as possible css/js from a CDN to offload the ESP. Currently (but it is only draft and basically mocking stuff) the size is 18Kb. Your version is taking 32Kb so should all be okay I guess.

I was wondering if you want this to be part of the `core`-project or if I should continue it for myself? Would like to have your input on this.

mrWheel, 2019-03-20:
Danny,

Ziet er eg goed uit.

Ik kom binnenkort met een redesign van de firmware.
Hier

https://youtu.be/VBA_aF7jNxo

Kun je een voorproefje zien.

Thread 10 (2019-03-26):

error: 'strcpy_P' was not declared in this scope

bakman2, 2019-03-26:
-edit

vaag, had eerst de zip van Time toegevoegd, die werkte niet, toen via de lib manager opnieuw installed, dat werkt wel, build goed, upload goed.
Nu alleen een "file not found" op het ip.

bakman2, 2019-03-26:
Solved. Nu alleen nog een "file not found" op het ip.

Closed 2019-03-26.

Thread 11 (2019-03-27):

FileNotFound

bakman2, 2019-03-27:
Alles lijkt te werken, json, csv’s, telnet stream.

Maar de index.html/js komt terug met FileNotFound

Ik heb de laatste versie van esp8266 geinstalleerd (2.5.0), upload werkt.

Is dit een SPIFSS issue?

bakman2, 2019-03-27:
Ok ik heb gevonden via je blog ergens op bladzijde 2. De instructies zouden iets efficienter kunnen.
Ik wil het eventueel wel herschijven voor wiki vorm als je daar voor open staat @mrWheel

mrWheel, 2019-03-27:
@bakman2 ,

Ik weet niet waar je problemen mee had. Waarschijnlijk de data map niet ge-upload? Blijkbaar staat het dus wel op mijn post maar is het moeilijk te vinden.
Als je wilt helpen alles duidelijk(er) te maken sta ik daar natuurlijk voor open. Dat is immers het idee van Open Source!

jicho, 2019-03-27:
@mrWheel :
> Als je wilt helpen alles duidelijk(er) te maken sta ik daar natuurlijk voor open. Dat is immers het idee van Open Source!

Misschien handig om de Wiki te activeren voor dit project? Kan in de basis de huidige PDF handleiding hier neergezet worden in markdown (of restructured text) en hij is, volgens mij, dan ook makkelijk aan te vullen door derden.

Idee?

mrWheel, 2019-03-27:
Hm....

Goed idee, maar ik moet even uitzoeken hoe dat moet.
Ga ik morgenmiddag mee aan de slag en kom daar bij je op terug.

Groet,

Willem

gsm: 0653 - 499 551
www: http://willem.aandewiel.nl/

---
Thank God I'm Atheist

Verstuurd vanaf mijn iPad

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

jicho, 2019-03-28:
Ben benieuwd of het lukt :)

Zou meteen een mooie zijn waar je FAQ's kwijt kunt!

mrWheel, 2019-03-28:
Wat wil je dat ik er instop?
De bouwbeschrijving?
Of zet je er -in eerste instantie- zelf in wat je nodig hebt?

Keep me posted!

Groet,

Willem

gsm: 0653 - 499 551
www: http://www.aandewiel.nl/
---
Love -- the last of the serious diseases of childhood.

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

bakman2, 2019-03-28:
Ik ben aan het schrijven, kort en bondig maar van A tot Z, in de hoop dat iedereen dit project kan maken :)

Mijn hobbels waren:
1) ESP01 flashen, dit niet vanzelfsprekend
2) SPIFFS, las er te snel/makkelijk overheen.

Ik ben geen electronica guru dus heb graag wat guidelines, dingen spreken voor mij niet altijd voor zich.

mrWheel, 2019-03-28:
Kun je mij een email adres geven?
Communiceert wat makkelijker.

Groet,

Willem

gsm: 0653 - 499 551
www: http://www.aandewiel.nl/
---
Time is but the stream I go a-fishing in. -- Henry David Thoreau

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

bakman2, 2019-03-28:
Dat is op zich prima, maar ik wil 'm alleen niet hier neerzetten. :#

mrWheel, 2019-03-28:
Zet dan even een comment op mijn website.
Ik haal het comment weer weg maar heb dan wel jou email adres!

Groet,

Willem

gsm: 0653 - 499 551
www: http://www.aandewiel.nl/
---
People who have what they want are very fond of telling people who haven't what they want that they don't want it. -- Ogden Nash

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

jicho, 2019-03-28:
@mrWheel ik zou sowieso de bouwinstructie plaatsen, scheelt een PDF genereren en is makkelijk te onderhouden.

bakman2, 2019-03-28:
Done @mrWheel

Closed 2019-03-27.

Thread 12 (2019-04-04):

DSMR 2.2 issues - Parsing never starts

mrvdb, 2019-04-04:
I'm using the kit as purchased from opencircuit.nl with the exception of having an external +5V soldered to the pins.

- Meter is the Kamstrup 382 (DSMR 2.2)
- changed serial settings to `Serial.begin(9600, SERIAL_7E1);` in the `setup()` function

The telegrams can be seen on a telnet session, so communication seems to work, the values makes sense.

Parsing never starts however, because the test [here](https://github.com/mrWheel/DSMRlogger2HTTP/blob/master/DSMRlogger2HTTP.ino#L814) never succeeds. (`reader.available()`)

Is anything else needed?

mrvdb, 2019-04-04:
Hmm, there's apparently no checksum in DSMR 2.2 after the '!' at the end.

So, the dsrm reader will never parse indeed then. Back to the drawing board for me. :-(

mrvdb, 2019-04-04:
I've created a workable solution (for me at least) which logs what is possible until I get a new meter.

For those interested: https://gist.github.com/mrvdb/ba197ea41f8c3ebfc61cb0979cadfdd7  holds the patch against the arduino-dsmr library to make it work.

I think the issue here can be closed, it's mostly a library issue.

Closed 2019-04-23.

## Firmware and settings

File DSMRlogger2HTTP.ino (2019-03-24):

/*
***************************************************************************  
**  Program  : DSMRlogger2HTTP
*/
#define _FW_VERSION "v0.7.7 (" +String( __DATE__) + " " + String(__TIME__) + ")"
/*
**  Copyright (c) 2019 Willem Aandewiel
**
**  TERMS OF USE: MIT License. See bottom of file.                                                            
***************************************************************************      
  Arduino-IDE settings for ESP01 (black):

    - Board: "Generic ESP8266 Module"
    - Flash mode: "DOUT"
    - Flash size: "1M (128K SPIFFS)"
    - Debug port: "Disabled"
    - Debug Level: "None"
    - IwIP Variant: "v2 Lower Memory"
    - Reset Method: "nodemcu"   // but will depend on the programmer!
    - Crystal Frequency: "26 MHz" 
    - VTables: "Flash"
    - Flash Frequency: "40MHz"
    - CPU Frequency: "80 MHz"
    - Buildin Led: "1"  // GPIO01 !! for ESP-01S USE "2"! Also the "S" has no red led
    - Upload Speed: "115200"
    - Erase Flash: "Only Sketch"
    - Port: "ESP01-DSMR at <-- IP address -->"
*/

/******************** change this for testing only **********************************/
// #define HAS_NO_METER       // define if No Smart Meter is attached
/******************** don't change enything below this comment **********************/

//  part of ESP8266 Core https://github.com/esp8266/Arduino
#include <ESP8266WiFi.h>        // version 1.0.0

//  part of ESP8266 Core https://github.com/esp8266/Arduino
#include <ESP8266WebServer.h>   // Version 1.0.0

//  https://github.com/tzapu/WiFiManager
#include <WiFiManager.h>        // version 0.14.0

//  part of ESP8266 Core https://github.com/esp8266/Arduino
#include <ArduinoOTA.h>         // Version 1.0.0

//  https://github.com/jandrassy/TelnetStream
#include <TelnetStream.h>       // Version 0.0.1

//  part of ESP8266 Core https://github.com/esp8266/Arduino
#include <FS.h>

//  https://github.com/PaulStoffregen/Time
#include <TimeLib.h>

//  https://github.com/matthijskooijman/arduino-dsmr
#include <dsmr.h>               // Version 0.1.0

#ifdef ARDUINO_ESP8266_NODEMCU
  #define VCC_ENABLE   14       // D3 = GPIO0, D5 = GPIO14, D6 = GPIO12
  #ifdef HAS_NO_METER
    #define HOSTNAME     "TEST-DSMR"
  #else
    #define HOSTNAME     "NODEMCU-DSMR"
  #endif
  //#define VCC_ENABLE    0     // <-- define valid GPIO-pin for DTR
#endif
#ifdef ARDUINO_ESP8266_GENERIC
  #ifdef HAS_NO_METER
    #define HOSTNAME     "TEST-DSMR"
  #else
    #define HOSTNAME     "ESP01-DSMR2"  // <<-- testing!!!!!
  #endif
  //#define VCC_ENABLE    0     // ESP01 does not have a free GPIO-pin
#endif
#ifdef HAS_NO_METER
    #define HOURS_FILE        "/TSThours.csv"
    #define WEEKDAY_FILE      "/TSTweek.csv"
    #define MONTHS_FILE       "/TSTmonths.csv"
#else
    #define HOURS_FILE        "/PRDhours.csv"
    #define WEEKDAY_FILE      "/PRDweek.csv"
    #define MONTHS_FILE       "/PRDmonths.csv"
#endif
#define MONTHS_CSV_HEADER "YYMM;   Energy Del;   Energy Ret;    Gas Del;\n"
#define HOURS_CSV_HEADER  "HR; Energy Del; Energy Ret;    Gas Del;\n"
#define LOG_FILE          "/logger.txt"
#define LOG_FILE_R        "/loggerR.txt"
#define NUMLASTLOG        3  
#define LED_ON            LOW
#define LED_OFF           HIGH

/**
 * Define the DSMRdata we're interested in, as well as the DSMRdatastructure to
 * hold the parsed DSMRdata. This list shows all supported fields, remove
 * any fields you are not using from the below list to make the parsing
 * and printing code smaller.
 * Each template argument below results in a field of the same name.
 */
using MyData = ParsedData<
  /* String */         identification
  /* String */        ,p1_version
  /* String */        ,timestamp
  /* String */        ,equipment_id
  /* FixedValue */    ,energy_delivered_tariff1
  /* FixedValue */    ,energy_delivered_tariff2
  /* FixedValue */    ,energy_returned_tariff1
  /* FixedValue */    ,energy_returned_tariff2
  /* String */        ,electricity_tariff
  /* FixedValue */    ,power_delivered
  /* FixedValue */    ,power_returned
//  /* FixedValue */    ,electricity_threshold
//  /* uint8_t */       ,electricity_switch_position
//  /* uint32_t */      ,electricity_failures
//  /* uint32_t */      ,electricity_long_failures
//  /* String */        ,electricity_failure_log
//  /* uint32_t */      ,electricity_sags_l1
//  /* uint32_t */      ,electricity_sags_l2
//  /* uint32_t */      ,electricity_sags_l3
//  /* uint32_t */      ,electricity_swells_l1
//  /* uint32_t */      ,electricity_swells_l2
//  /* uint32_t */      ,electricity_swells_l3
//  /* String */        ,message_short
//  /* String */        ,message_long
  /* FixedValue */    ,voltage_l1
  /* FixedValue */    ,voltage_l2
  /* FixedValue */    ,voltage_l3
  /* FixedValue */    ,current_l1
  /* FixedValue */    ,current_l2
  /* FixedValue */    ,current_l3
  /* FixedValue */    ,power_delivered_l1
  /* FixedValue */    ,power_delivered_l2
  /* FixedValue */    ,power_delivered_l3
  /* FixedValue */    ,power_returned_l1
  /* FixedValue */    ,power_returned_l2
  /* FixedValue */    ,power_returned_l3
  /* uint16_t */      ,gas_device_type
  /* String */        ,gas_equipment_id
//  /* uint8_t */       ,gas_valve_position
  /* TimestampedFixedValue */ ,gas_delivered
//  /* uint16_t */      ,thermal_device_type
//  /* String */        ,thermal_equipment_id
//  /* uint8_t */       ,thermal_valve_position
//  /* TimestampedFixedValue */ ,thermal_delivered
//  /* uint16_t */      ,water_device_type
//  /* String */        ,water_equipment_id
//  /* uint8_t */       ,water_valve_position
//  /* TimestampedFixedValue */ ,water_delivered
//  /* uint16_t */      ,slave_device_type
//  /* String */        ,slave_equipment_id
//  /* uint8_t */       ,slave_valve_position
//  /* TimestampedFixedValue */ ,slave_delivered
>;
 
//===========================================================================================
void displayHoursHist(bool);  // prototype (see MenuStuff tab)
void displayDaysHist(bool);   // prototype
void displayMonthsHist(bool); // prototype
void configModeCallback(WiFiManager *myWiFiManager);
void processData(MyData DSMRdata);
//===========================================================================================

typedef struct {
    uint16_t  Label;
    float     EnergyDelivered;
    float     EnergyReturned;
    float     GasDelivered;
} dataStruct;

static dataStruct hoursDat[10];    // 0 + 1-8
static dataStruct weekDat[9];      // 0 - 6 (0=sunday)
static dataStruct monthsDat[27];   // 0 + year1 1 t/m 12 + year2 1 t/m 12
static char *weekDayName[]  { "Zondag", "Maandag", "Dinsdag", "Woensdag"
                            , "Donderdag", "Vrijdag", "Zaterdag", "UnKnown" };
static char *monthName[]    { "00", "Januari", "Februari", "Maart", "April", "Mei", "Juni", "Juli"
                            , "Augustus", "September", "Oktober", "November", "December", "13" };
static char *flashMode[]    { "QIO", "QOUT", "DIO", "DOUT", "UnKnown" };

/**
struct FSInfo {
    size_t totalBytes;
    size_t usedBytes;
    size_t blockSize;
    size_t pageSize;
    size_t maxOpenFiles;
    size_t maxPathLength;
};
**/
static FSInfo SPIFFSinfo;

// Set up to read from the Serial port, and use VCC_ENABLE as the
// request pin. 
#ifdef VCC_ENABLE
  P1Reader reader(&Serial, VCC_ENABLE);
#else
  P1Reader reader(&Serial, 0);
#endif
;

WiFiClient        wifiClient;
ESP8266WebServer  server ( 80 );

uint32_t  waitLoop, noMeterWait, telegramCount, telegramErrors, waitForATOupdate;
char      cMsg[100], fChar[10];
char      APname[50], MAChex[13]; //n1n2n3n4n5n6\0
float     EnergyDelivered, EnergyReturned;
float     PowerDelivered, PowerReturned;
int32_t   PowerDelivered_l1, PowerDelivered_l2, PowerDelivered_l3;
int32_t   PowerReturned_l1,  PowerReturned_l2,  PowerReturned_l3;
float     GasDelivered;
String    pTimestamp;
String    P1_Version, Equipment_Id, GasEquipment_Id, ElectricityTariff;
char      Identification[150];
float     EnergyDeliveredTariff1, EnergyDeliveredTariff2, EnergyReturnedTariff1, EnergyReturnedTariff2;
float     Voltage_l1, Voltage_l2, Voltage_l3;
uint16_t  Current_l1, Current_l2, Current_l3;
uint16_t  GasDeviceType;

String    lastReset = "";
String    lastLogLine[NUMLASTLOG + 1]; 
bool      debug = true, OTAinProgress = false, Verbose = false, showRaw = false, SPIFFSmounted = false;
String    dateTime;
int8_t    thisHour = -1, thisWeekDay = -1, thisMonth = -1, lastMonth, thisYear = 15;
int8_t    testMonth = 0;
int8_t    tries, showRawCount;
uint32_t  nextSecond, unixTimestamp;
uint64_t  upTimeSeconds;
IPAddress ipDNS, ipGateWay, ipSubnet;
uint16_t  WIFIreStartCount;
String    jsonString;

struct showValues {
  template<typename Item>
  void apply(Item &i) {
    if (i.present()) {
        TelnetStream.print(Item::name);
        TelnetStream.print(F(": "));
        TelnetStream.print(i.val());
        TelnetStream.print(Item::unit());
        TelnetStream.println();
    }
  }
};


//===========================================================================================
String macToStr(const uint8_t* mac) {
//===========================================================================================
  String result;
  for (int i = 0; i < 6; ++i) {
    result += String(mac[i], 16);
    if (i < 5)
      result += ':';
  }
  return result;
} // macToStr()


//===========================================================================================
void escapeJson(const char * Src, char * Dest) {
  int p=0;

  if (Verbose) Serial.print("In[");
  for(int c=0; Src[c] != '\0'; c++) {
    if (Verbose) Serial.print(Src[c]);
    switch((char)Src[c]) {
      case '\\':  Dest[p++]='\\'; Dest[p++]='u'; Dest[p++]='0'; Dest[p++]='0'; Dest[p++]='5', Dest[p++]='c';  
                  break;
      case '/':   Dest[p++]='\\'; Dest[p++]='u'; Dest[p++]='0'; Dest[p++]='0'; Dest[p++]='2', Dest[p++]='f';
                  break;
      case '\b':  Dest[p++]='\\'; Dest[p++]='u'; Dest[p++]='0'; Dest[p++]='0'; Dest[p++]='0', Dest[p++]='8';
                  break;
      case '\f':  Dest[p++]='\\'; Dest[p++]='u'; Dest[p++]='0'; Dest[p++]='0'; Dest[p++]='0', Dest[p++]='c';
                  break;
      case '\n':  Dest[p++]='\\'; Dest[p++]='u'; Dest[p++]='0'; Dest[p++]='0'; Dest[p++]='0', Dest[p++]='d';
                  break;
      case '\r':  Dest[p++]='\\'; Dest[p++]='u'; Dest[p++]='0'; Dest[p++]='0'; Dest[p++]='0', Dest[p++]='a';
                  break;
      case '\t':  Dest[p++]='\\'; Dest[p++]='u'; Dest[p++]='0'; Dest[p++]='0'; Dest[p++]='0', Dest[p++]='9';
                  break;
      default:    Dest[p++]=Src[c];  
    }
  }
  Dest[p] = '\0';
  if (Verbose) Serial.print("] => Out[");
  for(int c=0; c < sizeof(Dest), Dest[c] != '\0'; c++) {
    if (Verbose) Serial.print(Dest[c]);
  }
  if (Verbose) Serial.println("]");
  
} // escapeJson()

//===========================================================================================
String upTime() {
//===========================================================================================

  char    calcUptime[20];

  sprintf(calcUptime, "%d(d):%02d:%02d", int((upTimeSeconds / (60 * 60 * 24)) % 365)
                                       , int((upTimeSeconds / (60 * 60)) % 24)
                                       , int((upTimeSeconds / (60)) % 60));

  return calcUptime;

} // upTime()


//===========================================================================================
void hourToSlot(int8_t h, int8_t &slot, int8_t &nextSlot, int8_t &prevSlot) {
//===========================================================================================
  switch(h) {
    case  0:
    case  1:
    case  2:  slot = 1; nextSlot = 2; prevSlot = 8; break;
    case  3:
    case  4:
    case  5:  slot = 2; nextSlot = 3; prevSlot = 1;  break;
    case  6:
    case  7:
    case  8:  slot = 3; nextSlot = 4; prevSlot = 2;  break;
    case  9:
    case 10:
    case 11:  slot = 4; nextSlot = 5; prevSlot = 3;  break;
    case 12:
    case 13:
    case 14:  slot = 5; nextSlot = 6; prevSlot = 4;  break;
    case 15:
    case 16:
    case 17:  slot = 6; nextSlot = 7; prevSlot = 5;  break;
    case 18:
    case 19:
    case 20:  slot = 7; nextSlot = 8; prevSlot = 6;  break;
    case 21:
    case 22:
    case 23:  slot = 8; nextSlot = 1; prevSlot = 7;  break;
    default:  slot = 8; nextSlot = 1; prevSlot = 7; 
  }

} // hourToSlot()


//===========================================================================================
void printData() {
//===========================================================================================

    TelnetStream.println("-Totalen----------------------------------------------------------");
    dateTime = buildDateTimeString(pTimestamp);
    sprintf(cMsg, "Datum / Tijd         :  %s", dateTime.c_str());
    TelnetStream.println(cMsg);

    dtostrf(EnergyDelivered, 9, 3, fChar);
    sprintf(cMsg, "Energy Delivered     : %skWh", fChar);
    TelnetStream.println(cMsg);

    dtostrf(EnergyReturned, 9, 3, fChar);
    sprintf(cMsg, "Energy Returned      : %skWh", fChar);
    TelnetStream.println(cMsg);

    dtostrf(PowerDelivered, 8, 0, fChar);
    sprintf(cMsg, "Power Delivered      : %skW", fChar);
    TelnetStream.println(cMsg);

    dtostrf(PowerReturned, 8, 0, fChar);
    sprintf(cMsg, "Power Returned       : %skW", fChar);
    TelnetStream.println(cMsg);
    
    dtostrf(PowerDelivered_l1, 8, 0, fChar);
    sprintf(cMsg, "Power Delivered (l1) : %sWatt", fChar);
    TelnetStream.println(cMsg);
    
    dtostrf(PowerDelivered_l2, 8, 0, fChar);
    sprintf(cMsg, "Power Delivered (l2) : %sWatt", fChar);
    TelnetStream.println(cMsg);
    
    dtostrf(PowerDelivered_l3, 8, 0, fChar);
    sprintf(cMsg, "Power Delivered (l3) : %sWatt", fChar);
    TelnetStream.println(cMsg);
    
    dtostrf(PowerReturned_l1, 8, 0, fChar);
    sprintf(cMsg, "Power Returned (l1)  : %sWatt", fChar);
    TelnetStream.println(cMsg);
    
    dtostrf(PowerReturned_l2, 8, 0, fChar);
    sprintf(cMsg, "Power Returned (l2)  : %sWatt", fChar);
    TelnetStream.println(cMsg);
    
    dtostrf(PowerReturned_l3, 8, 0, fChar);
    sprintf(cMsg, "Power Returned (l3)  : %sWatt", fChar);
    TelnetStream.println(cMsg);

    dtostrf(GasDelivered, 9, 2, fChar);
    sprintf(cMsg, "Gas Delivered        : %sm3", fChar);
    TelnetStream.println(cMsg);
    TelnetStream.println("==================================================================");
  
} // printData()


//===========================================================================================
void processData(MyData DSMRdata) {
//===========================================================================================
  int8_t slot, nextSlot, prevSlot;
  char   cID[100], cID2[100];
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
void loop () {
//===========================================================================================
  ArduinoOTA.handle();
  server.handleClient();
  handleKeyInput();

  if (!showRaw) {
    reader.loop();
  }
  
  if (!OTAinProgress) {
    if (!showRaw) {
      if (millis() > waitLoop) {
        //waitLoop = millis() + 10000;  // tien seconden?
        waitLoop = millis() + 2000;  // test 2 seconden

        reader.enable(true);
#ifdef ARDUINO_ESP8266_GENERIC
        digitalWrite(BUILTIN_LED, LED_ON);
#else
        digitalWrite(BUILTIN_LED, !digitalRead(BUILTIN_LED));
#endif
      }
    } 
  } else {  // waiting for ATO-update (or in progress) ...
      if (millis() > waitForATOupdate) {
        OTAinProgress     = false;
        waitForATOupdate  = millis();
      }
  }
  
#ifdef HAS_NO_METER
  // ---- create some dummy data for testing without a Slimme Meter connected (HAS_NO_METER is defined)
  static  MyData    DSMRdata;
  static  uint8_t   sMinute = 1, sHour = 20, sDay = 27, sMonth = 12, sYear = 16;
          char      testID[100];
          
  if (millis() > noMeterWait) {
    noMeterWait += 2000;

    strcpy(testID, "/ABCD(*)EFGHIJ(*)KLMNOPQRSTUVWXYZ");
    testID[6]  = '\\';
    testID[15] = '\t';
    escapeJson(testID, Identification);
    P1_Version                        = "TST";

    EnergyDelivered  += (float)(random(1, 50) / 15.0);
    EnergyReturned   += (float)(random(1, 40) / 55.0);
    GasDelivered     += (float)(random(1, 30) / 100.0);
    sMinute += 37;
    if (testMonth > 0) {
      sMonth   += testMonth;    
      sDay      = 10;
      testMonth = 0;
    }
    if (sMinute >= 60) {
      sMinute -= 59;
      sHour++;
    }
    if (sHour >= 24) {  // 0 .. 23
      sHour = 0;
      sDay += 3;
    }
    if (sDay >= 30) {
      sDay = (sDay % 30 ) + 1;
      sMonth++;
    }
    if (sMonth <  1) sMonth = 1;
    if (sMonth > 12) {
      sMonth = 1;
      sYear++;
    }

    telegramCount++;
    sprintf(cMsg, "%02d%02d%02d%02d%02d15S", sYear, sMonth, sDay, sHour, sMinute);
    pTimestamp = String(cMsg);
    TelnetStream.printf("pTimestamp [%s] sYear[%02d] sMonth[%02d] sDay[%02d] sHour[%02d] sMinute[%02d]\r\n"
                       , pTimestamp.c_str(), sYear,  sMonth,      sDay,      sHour,      sMinute);
    TelnetStream.flush();
    if (!OTAinProgress && !showRaw) {
      digitalWrite(BUILTIN_LED, !digitalRead(BUILTIN_LED));
      processData(DSMRdata);
    }

  } // noMeterWait > millis()

#else
  //---- this part is only processed when HAS_NO_METER is not defined!
  if (!OTAinProgress) {
    if (showRaw) {
      while(Serial.available() > 0) {
        char rIn = Serial.read();
        if (rIn == '!') showRawCount++;
        TelnetStream.write((char)rIn);
      }
      if (showRawCount > 20) {
        showRaw = false;
      }
    } else {
      if (reader.available()) {
        ArduinoOTA.handle();

        //-- declaration of DSMRdata must be in 
        //-- if-statement so it will be initialized
        //-- in every itteration (don't know how else)
        MyData    DSMRdata;
        String    DSMRerror;

        TelnetStream.println("\n==================================================================\r");
        TelnetStream.printf("read telegram [%d]\r\n", ++telegramCount);
        Serial.printf("read telegram [%d]\n", ++telegramCount);

        if (reader.parse(&DSMRdata, &DSMRerror)) {  // Parse succesful, print result
          digitalWrite(BUILTIN_LED, LED_OFF);
          processData(DSMRdata);
          if (Verbose) {
            DSMRdata.applyEach(showValues());
            printData();
          }
        } else {                                    // Parser error, print error
          TelnetStream.printf("Parse error %s\r\n", DSMRerror.c_str());
          telegramErrors++;
        }
        
      } // if (reader.available()) 
    }
  } // if (!OTAinProgress) 
#endif

  if (millis() > nextSecond) {
    nextSecond += 1000; // nextSecond is ahead of millis() so it will "rollover" 
    upTimeSeconds++;    // before millis() and this will probably work just fine
  }

} // loop()



/***************************************************************************
*
* Permission is hereby granted, free of charge, to any person obtaining a
* copy of this software and associated documentation files (the
* "Software"), to deal in the Software without restriction, including
* without limitation the rights to use, copy, modify, merge, publish,
* distribute, sublicense, and/or sell copies of the Software, and to permit
* persons to whom the Software is furnished to do so, subject to the
* following conditions:
*
* The above copyright notice and this permission notice shall be included
* in all copies or substantial portions of the Software.
*
* THE SOFTWARE IS PROVIDED "AS IS", WITHOUT WARRANTY OF ANY KIND, EXPRESS
* OR IMPLIED, INCLUDING BUT NOT LIMITED TO THE WARRANTIES OF
* MERCHANTABILITY, FITNESS FOR A PARTICULAR PURPOSE AND NONINFRINGEMENT.
* IN NO EVENT SHALL THE AUTHORS OR COPYRIGHT HOLDERS BE LIABLE FOR ANY
* CLAIM, DAMAGES OR OTHER LIABILITY, WHETHER IN AN ACTION OF CONTRACT, TORT
* OR OTHERWISE, ARISING FROM, OUT OF OR IN CONNECTION WITH THE SOFTWARE OR
* THE USE OR OTHER DEALINGS IN THE SOFTWARE.
* 
***************************************************************************/

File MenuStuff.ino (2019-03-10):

/*
***************************************************************************  
**  Program  : MenuStuff, part of DSMRlogger2HTTP
**  Version  : v0.7.8
**
**  Copyright (c) 2019 Willem Aandewiel
**
**  TERMS OF USE: MIT License. See bottom of file.                                                            
***************************************************************************      
*/

//===========================================================================================
void displayDaysHist(bool Telnet=true) {
//===========================================================================================
  char ED[20], ER[20], GD[20], today;
  int thisDay = weekday(unixTimestamp) - 1;
  int Label;

  if (Telnet) TelnetStream.println("\n======== WeekDay History ==========\r\n");

  for (int i=0; i<7; i++) {
    if (i == thisDay) today = '*';
    else              today = ' ';
    Label = weekDat[i].Label;
    dtostrf(weekDat[i].EnergyDelivered, 9, 3, ED);
    dtostrf(weekDat[i].EnergyReturned, 9, 3, ER);
    dtostrf(weekDat[i].GasDelivered, 8, 2, GD);
    sprintf(cMsg, "[%02d][%02d]%c Energy Del.[%s], Ret.[%s], Gas Del.[%s]\r", i, Label, today
                                                                            , ED, ER, GD);
    if (Telnet) TelnetStream.println(cMsg);
  }
  TelnetStream.flush();
  
} // displayDaysHist()


//===========================================================================================
void displayHoursHist(bool Telnet=true) {
//===========================================================================================
  char ED[20], ER[20], GD[20], hour;
  int thisHour = HourFromTimestamp(pTimestamp);
  int Label;
  
  if (Telnet) TelnetStream.println("\n======== Hours History ==========\r\n");
  for (int i=1; i<=8; i++) {
    if (i == thisHour)  hour = '*';
    else                hour = ' '; 
    Label = hoursDat[i].Label;
    dtostrf(hoursDat[i].EnergyDelivered, 9, 3, ED);
    dtostrf(hoursDat[i].EnergyReturned, 9, 3, ER);
    dtostrf(hoursDat[i].GasDelivered, 8, 2, GD);
    sprintf(cMsg, "[%02d][%02d]%c Energy Del.[%s], Ret.[%s], Gas Del.[%s]\r", i, Label, hour
                                                                          , ED, ER, GD);
    if (Telnet) TelnetStream.println(cMsg);

  }
  TelnetStream.flush();

} // displayHoursHist()


//===========================================================================================
void displayMonthsHist(bool Telnet=true) {
//===========================================================================================
  char ED[20], ER[20], GD[20], signal;
  int thisMonth = MonthFromTimestamp(pTimestamp);
  int thisYear  = YearFromTimestamp(pTimestamp);
  int Label;
  
  if (Telnet) TelnetStream.println("\n======== Months History ==========\r\n");
  for (int i=1; i<=24; i++) {
    Label = monthsDat[i].Label;
    dtostrf(monthsDat[i].EnergyDelivered, 9, 3, ED);
    dtostrf(monthsDat[i].EnergyReturned, 9, 3, ER);
    dtostrf(monthsDat[i].GasDelivered, 8, 2, GD);
    sprintf(cMsg, "[%02d][%04d] Energy Del.[%s], Ret.[%s], Gas Del.[%s]\r", i, Label
                                                                          , ED, ER, GD);
    if (Telnet) TelnetStream.println(cMsg);

  }
  TelnetStream.flush();

} // displayMonthsHist()


//===========================================================================================
void displayBoardInfo() {
//===========================================================================================
  TelnetStream.println("\r\n==================================================================\r");
  TelnetStream.print(" \r\n               (c)2018 by [Willem Aandewiel (www.aandewiel.nl)");
  TelnetStream.print("]\r\n         Firmware Version [");  TelnetStream.print( _FW_VERSION );
  TelnetStream.print("]\r\n                 Compiled [");  TelnetStream.print( __DATE__ ); 
                                                           TelnetStream.print( "  " );
                                                           TelnetStream.print( __TIME__ );
  TelnetStream.print("]\r\n      Telegrams Processed [");  TelnetStream.print( telegramCount );
  TelnetStream.print("]\r\n              With Errors [");  TelnetStream.print( telegramErrors );
  TelnetStream.print("]\r\n                 FreeHeap [");  TelnetStream.print( ESP.getFreeHeap() );
  TelnetStream.print("]\r\n                  Chip ID [");  TelnetStream.print( ESP.getChipId(), HEX );
  TelnetStream.print("]\r\n             Core Version [");  TelnetStream.print( ESP.getCoreVersion() );
  TelnetStream.print("]\r\n              SDK Version [");  TelnetStream.print( ESP.getSdkVersion() );
  TelnetStream.print("]\r\n           CPU Freq (MHz) [");  TelnetStream.print( ESP.getCpuFreqMHz() );
  TelnetStream.print("]\r\n         Sketch Size (kB) [");  TelnetStream.print( ESP.getSketchSize() / 1024.0 );
  TelnetStream.print("]\r\n   Free Sketch Space (kB) [");  TelnetStream.print( ESP.getFreeSketchSpace() / 1024.0 );

  if ((ESP.getFlashChipId() & 0x000000ff) == 0x85) 
        sprintf(cMsg, "%08X (PUYA)", ESP.getFlashChipId());
  else  sprintf(cMsg, "%08X", ESP.getFlashChipId());
  TelnetStream.print("]\r\n            Flash Chip ID [");  TelnetStream.print( cMsg );
  TelnetStream.print("]\r\n     Flash Chip Size (kB) [");  TelnetStream.print( ESP.getFlashChipSize() / 1024 );
  TelnetStream.print("]\r\nFlash Chip Real Size (kB) [");  TelnetStream.print( ESP.getFlashChipRealSize() / 1024 );
  TelnetStream.print("]\r\n         Flash Chip Speed [");  TelnetStream.print( ESP.getFlashChipSpeed() / 1000 / 1000 );
  FlashMode_t ideMode = ESP.getFlashChipMode();
  TelnetStream.print("]\r\n          Flash Chip Mode [");  TelnetStream.print( flashMode[ideMode] );

  TelnetStream.println("]\r");

  TelnetStream.println("==================================================================");
  TelnetStream.print(" \r\n               Board type [");
#ifdef ARDUINO_ESP8266_NODEMCU
    TelnetStream.print("ESP8266_NODEMCU");
#endif
#ifdef ARDUINO_ESP8266_GENERIC
    TelnetStream.print("ESP8266_GENERIC");
#endif
#ifdef ESP8266_ESP01
    TelnetStream.print("ESP8266_ESP01");
#endif
#ifdef ESP8266_ESP12
    TelnetStream.print("ESP8266_ESP12");
#endif
  TelnetStream.print("]\r\n                     SSID [");  TelnetStream.print( WiFi.SSID() );
  TelnetStream.print("]\r\n                  PSK key [");  TelnetStream.print( WiFi.psk() );
  TelnetStream.print("]\r\n               IP Address [");  TelnetStream.print( WiFi.localIP() );
  TelnetStream.print("]\r\n                 Hostname [");  TelnetStream.print( HOSTNAME );
  TelnetStream.print("]\r\n                   upTime [");  TelnetStream.print( upTime() );
  TelnetStream.println("]\r");
  TelnetStream.println("==================================================================\r\n");
  TelnetStream.flush();

} // displayBoardInfo()
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

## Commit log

2018-09-06 Version 5
    [hours.csv, months.csv, weekDay.csv]
2018-09-06 Create pcb1
2018-09-10 ESP.restart() replaced by ESP.reset()
    [WiFiStuff.ino]
2018-09-14 Display Version and Compile Date
    [hours.csv, months.csv, weekDay.csv]
2018-09-14 Hotfix for problems with the PUYA chips
    See:
    https://github.com/letscontrolit/ESPEasy/issues/748
    https://github.com/esp8266/Arduino/issues/4061
    .. and many more ..
    Place this file (on MacOS) in:
    “../Arduino../packages/esp8266/hardware/esp8266/2.4.2/cores/esp8266/“
    [Esp.cpp]
2018-09-16 More info in Board Type menu-option
2018-09-21 Resolved lots of small problems - Fairly Stable now
    [PRDhours.csv, PRDmonths.csv, PRDweek.csv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]
2018-09-24 No longer a problem with IDE 1.8.6 or 1.8.7
    [DSMRlogger2HTTP.ino]
2018-09-28 Duidelijker aangegeven wat uit de ESP8266 Core komt
2018-10-10 Removed bug that made NODEMCU crash with 1MB SPIFFS (or more)
    [SPIFFSstuff.ino]
2018-11-13 Version 3.0 of the PCB
    [DSMRlogger_v3-B.Cu.gbr, DSMRlogger_v3-B.Mask.gbr, DSMRlogger_v3-B.Paste.gbr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]
2018-12-02 Gerard te Meerman
    [bovenplaat slimme meterrj12.scad, bovenplaat slimme meterrj12.stl, kastje voor slimme meter rj12 variant-1.stl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]
2019-05-02 Laatste verbeteringen aan de documentatie
